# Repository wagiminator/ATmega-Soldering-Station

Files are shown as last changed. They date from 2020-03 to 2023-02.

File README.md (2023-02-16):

## !!! Warning: the version with "t" is the test version, there may be stability problems! Not recommended for production environments
## !!! 警告：带有“t”的是测试版本，可能存在稳定性问题！不建议用于生产环境

# 1. Overview
T12 焊台控制器功能介绍
T12 Quick Heating Soldering Station featuring
- 烙铁头温度实时监测
- Temperature measurement of the tip
- PID温度控制
- Direct or PID control of the heater
- 可以通过编码器进行控制温度
- Temperature control via rotary encoder
- 短按编码器进入短时升温模式
- Boost mode by short pressing rotary encoder switch
- 长按编码器进入主菜单
- Setup menu by long pressing rotary encoder switch
- 手柄震动检测（需要手柄含有震动传感器）
- Handle movement detection (by checking ball switch)
- 手柄连接检测（通过判断烙铁头温度是否能够被读取来实现）
- Iron unconnected detection (by idenfying invalid temperature readings)
- 定时器设定 - 随眠，关机时间
- Time driven sleep/power off mode if iron is unused (movement detection)
- 可以测量主控芯片电压以及温度
- Measurement of input voltage, Vcc and ATmega's internal temperature
- 在OLED上实现信息显示
- Information display on OLED
- 支持无源蜂鸣器
- Buzzer
- 允许设置不同烙铁头的温度校准值
- Calibrating and managing different soldering tips
- 设置被保存在EEPROM，掉电不丢失
- Storing user settings into the EEPROM
- 允许热插拔烙铁头，并弹出烙铁头配置选择菜单
- Tip change detection
- Support for N-Channel and P-Channel MOSFETs

## =========UI upgraded version =========

- 芯片过热以及低电压报警
- Chip overheating and low voltage alarm
- 更好的实时温度条以及实时功率条
- Better real-time temperature bar and real-time power bar
- 拥有过渡动画
- Have transition animation
- 内置屏幕保护程序
- Built in screen saver
- 屏幕翻转设置
- Screen flip settings
- 内置英文、中文语言包
- Built in English and Chinese language pack
- 开机密码设置
- System Password
- 允许设置旋钮方向
- Knob direction setting menu
- 内嵌看门狗，宕机自动重启
- Watchdog timer automatic reset the MCU

## V1.8t7 New features:

- EEPROM可用性检查机制
- EEPROM availability check

- 允许保存最大30个烙铁头的配置
- Tip change detection30 preservable soldering tip configurations

- 9段温度曲线拟合
- 9 segments of temperature curve fitting

## Links:
- Project Video: https://youtu.be/I9ATDxvQ1Bc
- Video from John Glavinos (electronics4all): https://youtu.be/4YDcWfOQmz4
- Video from LHW-createskyblue (UI-v1.6L): https://b23.tv/LiOe54
- T245 version with P-channel MOSFET by TaaraLabs: https://taaralabs.eu/atmega-t245/

# 2. Versions, Upgrades and Notes

## Soldering Station v2.0:




## Soldering Station v2.5:




## Soldering Station v2.6:




## UI-V1.8t6 UI Upgrade by createskyblue & lihaoyun6

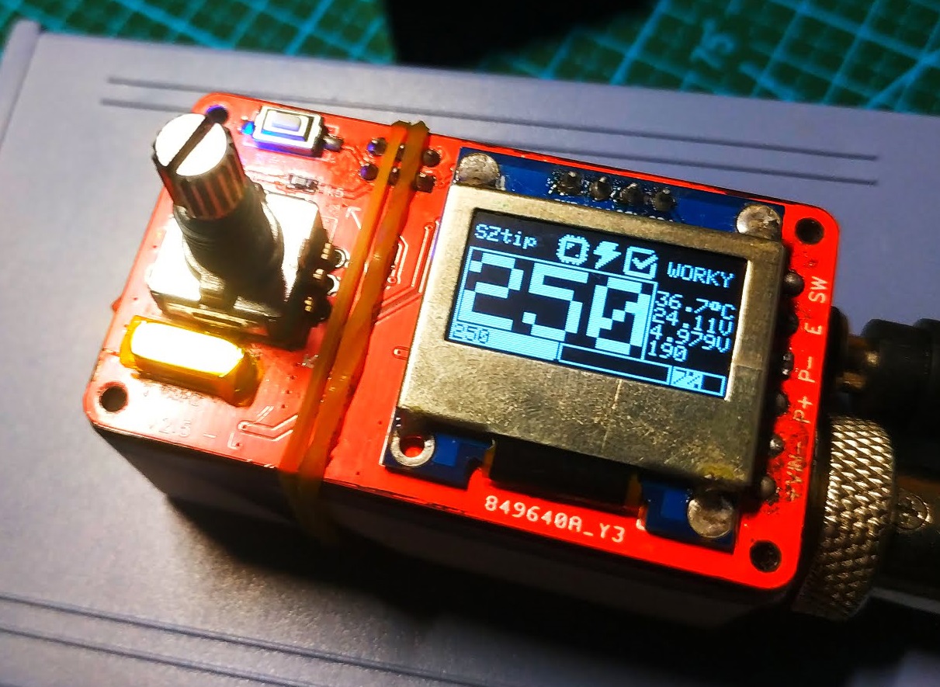
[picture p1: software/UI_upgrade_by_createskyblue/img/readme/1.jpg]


### Default control interface

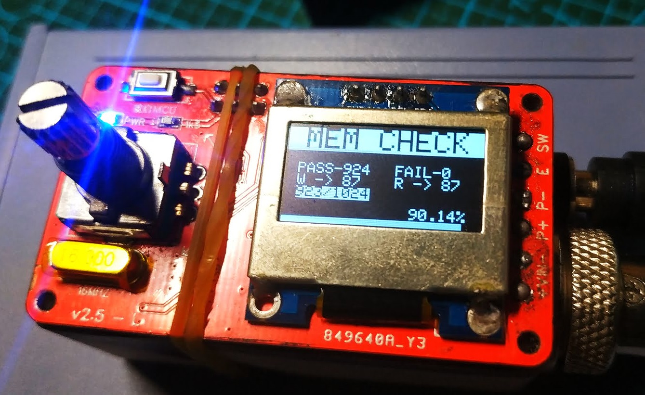
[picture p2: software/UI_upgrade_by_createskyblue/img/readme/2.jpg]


### EEPROM availability check

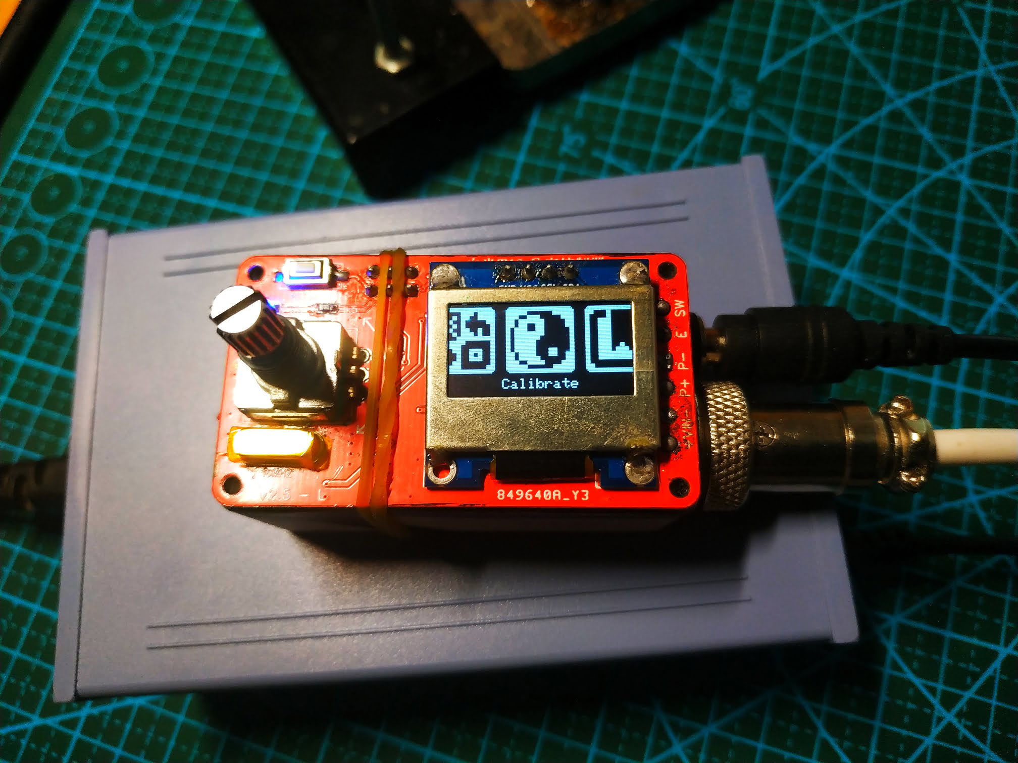
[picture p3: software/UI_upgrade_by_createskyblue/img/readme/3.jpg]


### Tip menu

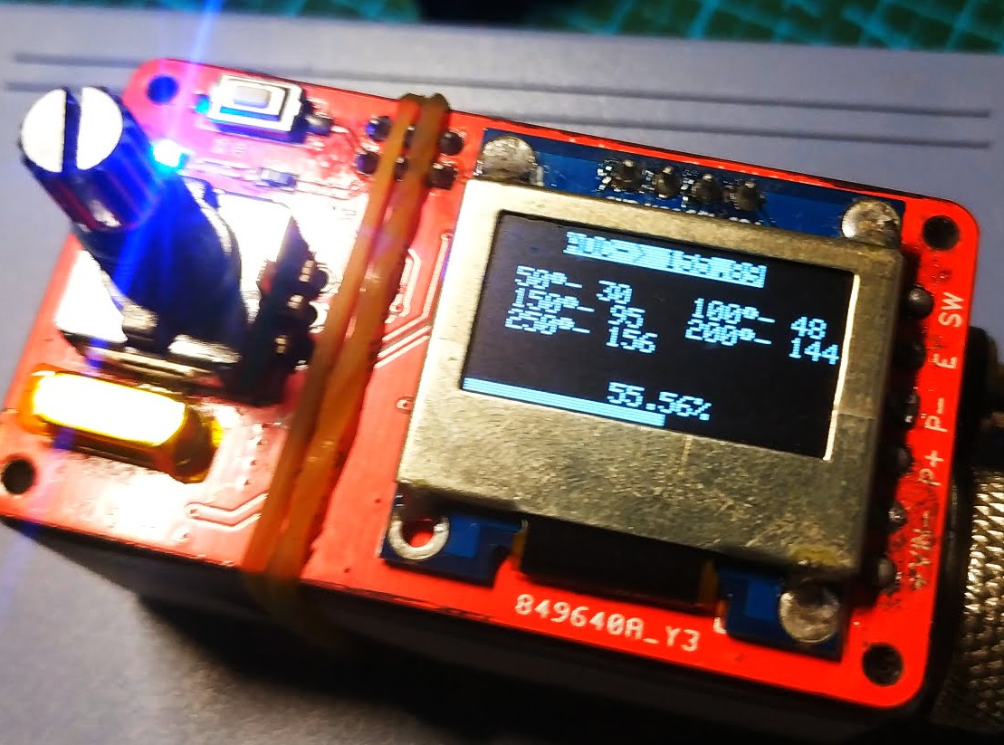
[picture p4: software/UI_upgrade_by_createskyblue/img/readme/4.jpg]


### 9 segments of temperature curve fitting & Soldering tip calibration page

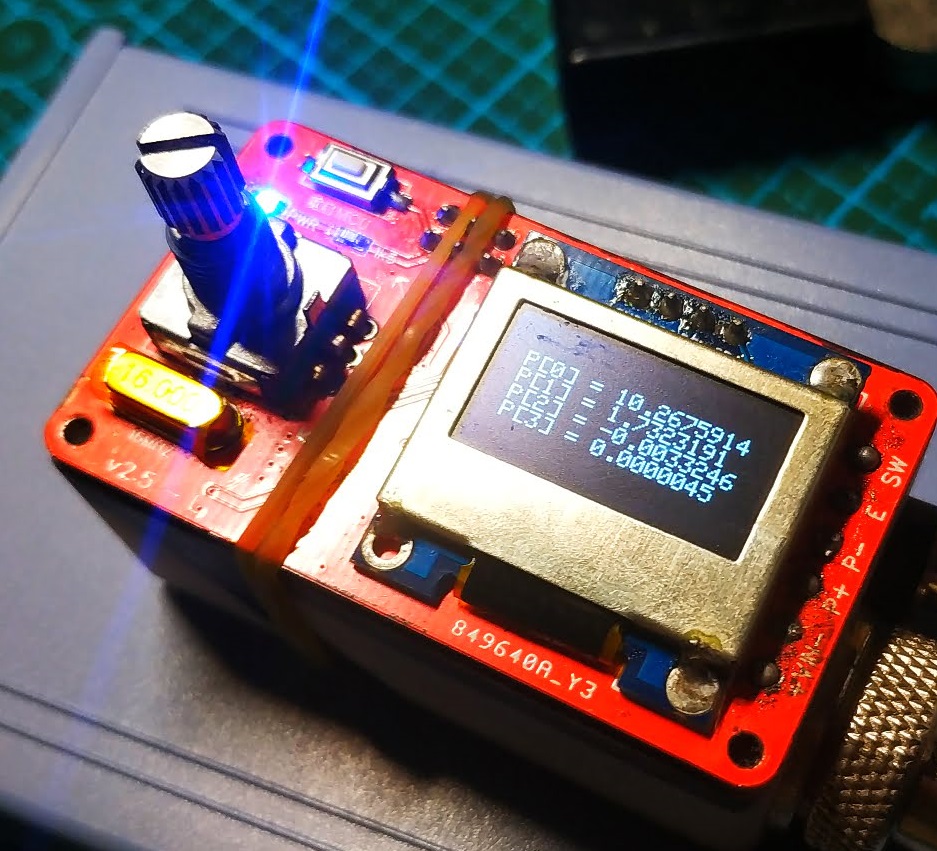
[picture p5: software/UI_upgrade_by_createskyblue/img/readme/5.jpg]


### Temperature calibration coefficient

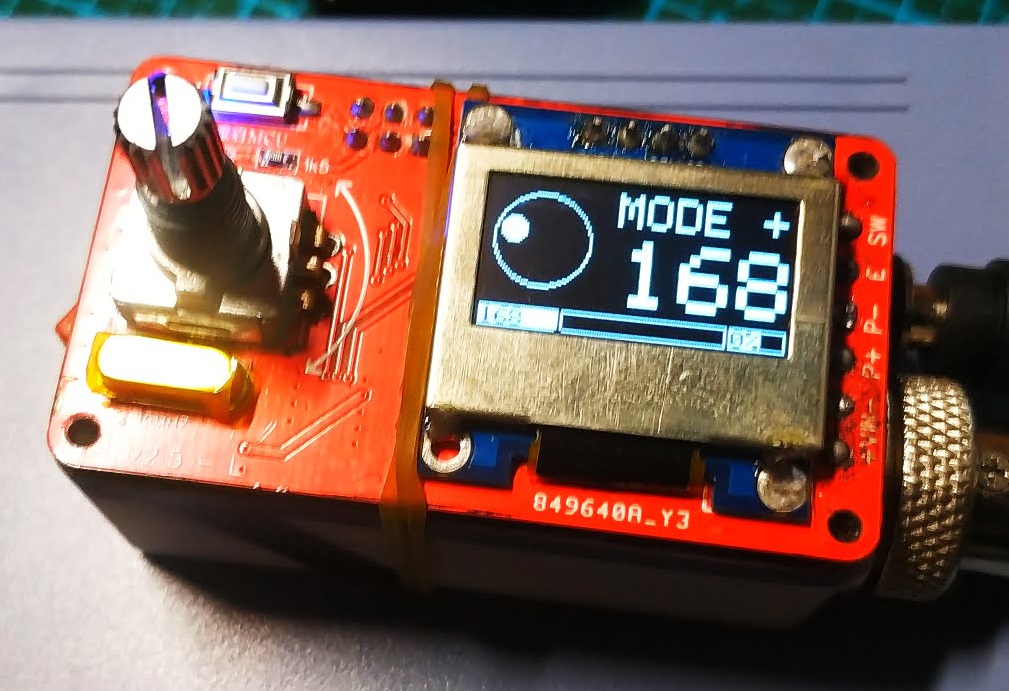
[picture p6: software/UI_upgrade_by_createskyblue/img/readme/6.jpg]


### Encoder direction regulation

Video from LHW-createskyblue (UI-v1.6L): https://b23.tv/LiOe54
	






## Notes and Errors

- In the board version 2.5 the diode D1 may overheat. To be on the safe side, the 18V zener diode D4 should be removed and the soldering station should be operated with a maximum of 20V. Alternatively, the diode D1 can be replaced with an SS54 schottky diode and the BJT Q1 with an FMMT619. 

# 3. Power Supply Specification Requirements #

Choose a power supply with an output voltage between 12V and 24V which can provide an output current according to the table below. The power supply must be well stabilized. The current and power is determined by the resistance (R = 8 Ohm) of the heater.

|Voltage (U)|Current (I) = U / R|Power (P) = U² / R|
|-|-|-|
|12 V|1.50 A|18 W|
|13 V|1.63 A|21 W|
|14 V|1.75 A|25 W|
|15 V|1.88 A|28 W|
|16 V|2.00 A|32 W|
|17 V|2.13 A|36 W|
|18 V|2.25 A|41 W|
|19 V|2.38 A|45 W|
|20 V|2.50 A|50 W|
|21 V|2.63 A|55 W|
|22 V|2.75 A|61 W|
|23 V|2.88 A|66 W|
|24 V|3.00 A|72 W|

# 4. Temperature Measurement and OpAmp Considerations #

A thermocouple (temperature sensor) is located in the T12 soldering tip. It creates a very small voltage depending on the temperature difference between the hot end and the cold junction (about 22 microvolts per degree Celsius). To measure this, the heater must be switched off since both share the same connections. The low voltage is amplified by the OpAmp and measured by the ADC of the microcontroller. The LMV358 is a very cheap and versatile OpAmp, but not the ideal choice for this task because it has a fairly high input offset voltage and is quite noisy. Although the SolderingStation also works with this OpAmp thanks to the software's smoothing and calibration algorithms, I highly recommend spending a little more money in a better one. The OPA2330AIDR or OPA2333AIDR for instance have the same pinout and can also be used with this board. They provide significantly more accurate and stable temperature measurements.






# 5. Heater High Side Switch with N-Channel MOSFET and Charge Pump #

The microcontroller switches the heater on and off via the MOSFET. Since the temperature measurement must be done over the same line and against ground, the MOSFET has to be placed between the supply voltage and the heater (high-side switch). A P-Channel MOSFET is normally used for this configuration. However, N-Channel MOSFETs usually have a lower resistance (RDS (on)), in the case of the IRLR7843 only 3 milliohms. A low resistance means a higher efficiency and a lower heat development of the MOSFET. For an N-channel MOSFET to function as a high-side switch, an additional circuit is required to maintain a positive GATE-TO-SOURCE voltage after the MOSFET is switched on. This is done using a so-called charge pump consisting of a capacitor and a diode. The principle of operation is illustrated in the following graphic by [Smallp Tsai](https://github.com/SmallpTsai):




# 6. Building Instructions #

In addition to the components for the PCB you will need the following:

- 3D-printed case
- Aviator Plug (4- or 5-pin depending on your iron handle)
- DC Power Jack (5.5 * 2.1 mm)
- Rocker Switch (KCD1 15 * 10 mm)
- Some wires
- 4 Self-tapping screws (2.3 * 5 mm)




Make sure that all parts fit nicely into the case. Solder the wires to the connectors and protect them with heat shrinks. Use thick wires (AWG18) for the power connections. Make all connections according to the schematic down below but keep in mind, that there's no standard pinout. Solder the wires directly to the corresponding pads on the pcb. To make the soldering station ESD-safe, connect the earth (E) terminal of the aviator plug to a female dupont connector and glue it into the corresponding opening on the case. Now you can connect the soldering station via a male dupont connector to an earth terminal. Upload the firmware and screw the pcb on top of the case.



The pinout shown works for the [Quecoo handles from aliexpress](https://aliexpress.com/wholesale?SearchText=quecoo+handle). Different handles may have different pinouts. If you are assembling your handle yourself, follow the scheme shown below. The video by [John Glavinos (electronics4all)](https://www.youtube.com/watch?v=DcmiFfuZw38) shows how it's done.



# 7. License #



This work is licensed under Creative Commons Attribution-ShareAlike 3.0 Unported License. 
(http://creativecommons.org/licenses/by-sa/3.0/)

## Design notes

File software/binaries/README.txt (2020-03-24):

avrdude -c usbtiny -p m328p -V -U lfuse:w:0xff:m -U hfuse:w:0xdb:m -U efuse:w:0xfd:m
avrdude -c usbtiny -p m328p -U flash:w:<name>.hex

re2: rotary encoder with 2 increments/step
re4: rotary encoder with 4 increments/step

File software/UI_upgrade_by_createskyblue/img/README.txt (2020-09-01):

感谢 千年板蓝根(github: lihaoyun6) 提供的字体文件以及相关素材！！！
Thanks for the font files and related materials provided by 千年板蓝根 (GitHub: lihaoyun6)!!!

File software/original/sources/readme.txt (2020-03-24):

Libraries:
https://github.com/olikraus/u8glib
https://github.com/mblythe86/C-PID-Library/tree/master/PID_v1

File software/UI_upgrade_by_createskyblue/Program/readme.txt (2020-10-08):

*重要提示 Important note

版本号含有"t"的代表是测试版本，不稳定不推荐上传
A version number with a "t" indicates a test version, and unstable uploads are not recommended

版本号含有多个"+" 代表是改进版本
The version number contains multiple "+" to indicate an improved version

Upload:
固件上传指令
avrdude -c usbtiny -p m328p -V -U lfuse:w:0xff:m -U hfuse:w:0xdb:m -U efuse:w:0xfd:m
avrdude -c usbtiny -p m328p -U flash:w:<name>.hex

Libraries:
用到的库文件
https://github.com/createskyblue/Arduboy2/
https://github.com/mblythe86/C-PID-Library/tree/master/PID_v1

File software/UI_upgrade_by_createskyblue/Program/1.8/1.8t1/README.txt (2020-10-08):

*1.8t1  国庆节更新目标*

1.调整简约模式的界面设计
2.加入编码器方向设定界面

3.加入自定义界面模式

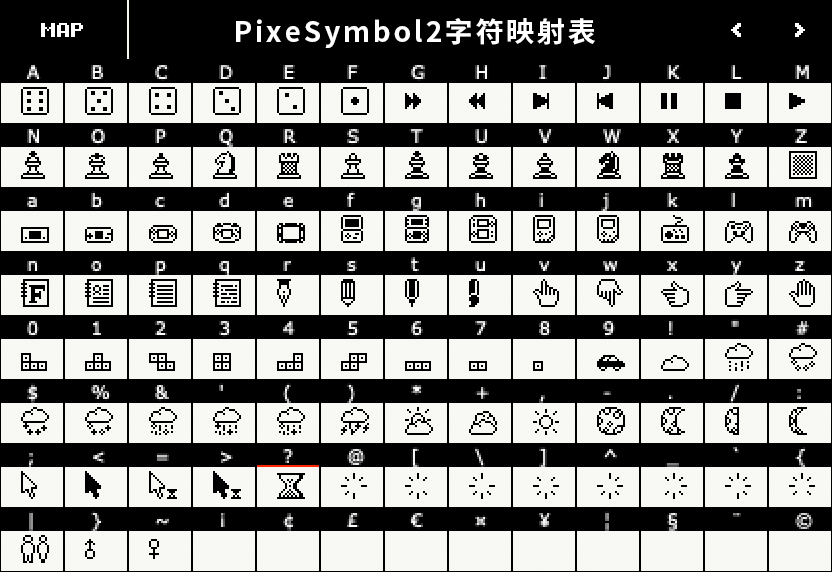
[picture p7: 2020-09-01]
software/UI_upgrade_by_createskyblue/img/PixeSymbol2字符映射表.png

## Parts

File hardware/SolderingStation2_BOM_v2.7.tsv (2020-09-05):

ID | Name | Designator | Footprint | Quantity | Manufacturer Part | Manufacturer | Supplier | Supplier Part | LCSC Assembly
1 | 1N4148W | D2 | DIODE-SOD-123 | 1 | 1N4148W-E3-08 | Vishay Intertech | LCSC | C241939
2 | LMV358IDR | U3 | SOP-8_150MIL | 1 | LMV358IDR | TI | LCSC | C63813 | Yes
3 | 16MHZ | X1 | HC-49S | 1 | X49SD16MSD2SI | Yangxing Tech | LCSC | C188201
4 | MLT-5030 | BUZZER1 | MLT-5030 | 1 | MLT-5030 | HNDZ | LCSC | C95297
5 | OLED | OLED | I2C - OLED 0.96" 128X64 | 1 | SSD1306 I2C OLED
6 | 18V | D4 | ZENER-SOD-123 | 1 | MM1Z18 | Jingdao | LCSC | C116111 | Yes
7 | 5V1 | D3 | ZENER-SOD-123 | 1 | MM1Z5V1 | SEMTECH | LCSC | C81601 | Yes
8 | 47k | R12 | 0603 | 1 | 0603WAF4702T5E | UniOhm | LCSC | C25819
9 | 1k5 | R2 | 0603 | 1 | 0603WAF1501T5E | UniOhm | LCSC | C22843
10 | 10k | R11,R13,R3,R4,R6,R7,R14,R10,R1 | 0603 | 9 | 0603WAF1002T5E | UniOhm | LCSC | C25804
11 | 1k | R9 | 0603 | 1 | 0603WAF1001T5E | UniOhm | LCSC | C21190
12 | 200k | R8 | 0603 | 1 | 0603WAF2003T5E | UniOhm | LCSC | C25811
13 | IRLR7843TRPBF | Q2 | TO-252-2 | 1 | IRLR7843TRPBF | IR | LCSC | C21988 | Yes
14 | KF350-3.5mm | P3,P2,P1 | KF350-2P | 3 | WJ2EDGVC-5.08-2P | ReliaPro | LCSC | C8445
15 | ICSP-6 | ICSP | ICSP-6 | 1 | ?
16 | 3x6x2.5 | RESET | KEY-3.0*6.0 | 1 | 3x6x2.5Red head high temperature | ReliaPro | LCSC | C46491
17 | Rotary Enc | SW1 | BOURNS_PEC11R-4XXXF-SXXXX | 1 | PEC11R-4015F-S0024 | BOURNS | LCSC | C143789
18 | 100n | C10,C1,C9,C3,C2 | 0603 | 5 | CC0603KRX7R9BB104 | YAGEO | LCSC | C14663
19 | 1u | C13 | 0603 | 1 | CL10A105KB8NNNC | SAMSUNG | LCSC | C15849
20 | 330n | C11 | 0603 | 1 | C1608X7R1H334KT000E | TDK | LCSC | C76621
21 | 22p | C5,C6 | 0603 | 2 | CL10C220JB8NNNC | SAMSUNG | LCSC | C1653
22 | 2n2 | C8 | 0603 | 1 | 0603B222K500NT | FH | LCSC | C1604
23 | 1k | R5 | 1206 | 1 | 1206W4F1001T5E | UniOhm | LCSC | C4410
24 | 47u | C4 | 1206 | 1 | 1206F476M100NT | FH | LCSC | C30349
25 | 22u | C12 | 1206 | 1 | C3216X5R1V226MTJ00E | TDK | LCSC | C342620
26 | 10u | C7 | 1206 | 1 | GMK316BJ106KL-T | Taiyo Yuden | LCSC | C92797
27 | 78M05 | U2 | TO-252-2 | 1 | ME78M05K3G | MICRONE | LCSC | C83969 | Yes
28 | PWR | LED1 | LED0603 | 1 | 19-217/BHC-ZL1M2RY/3T | EVERLIGHT | LCSC | C72041
29 | FMMT619 | Q1 | SOT-23-3_L2.9-W1.6-P1.90-LS2.8-BR | 1 | FMMT619 | CJ | LCSC | C53071 | Yes
30 | SS54 | D1 | DIODE-SMA(DO-214AC) | 1 | SS54 | Jingdao | LCSC | C123946 | Yes
31 | ATMEGA328P-AU | U1 | TQFP-32_7X7X08P | 1 | ATMEGA328P-AU | MICROCHIP | LCSC | C14877 | Yes

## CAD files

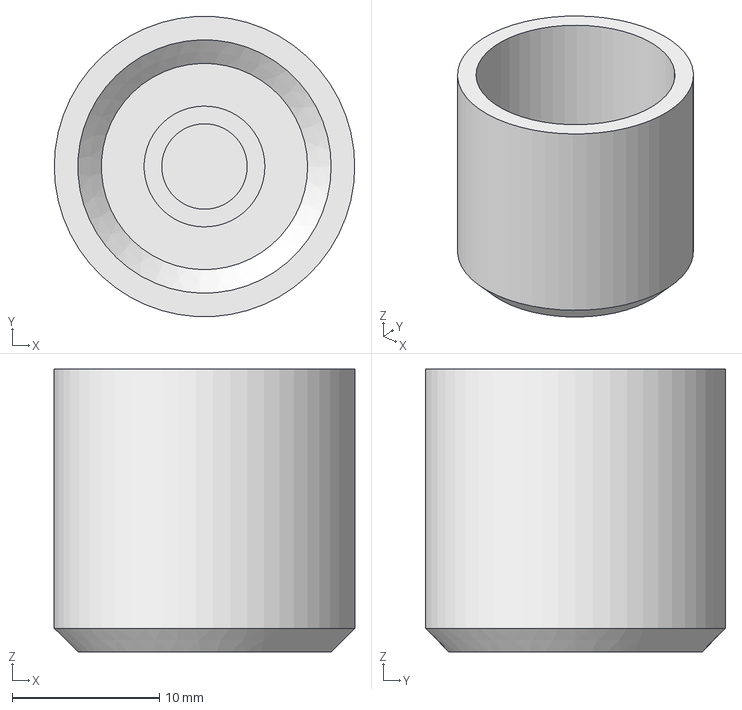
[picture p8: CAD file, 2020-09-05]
3dprint/SolderingStationV2_knob.fcstd
20.4 x 20.4 x 19.2 mm

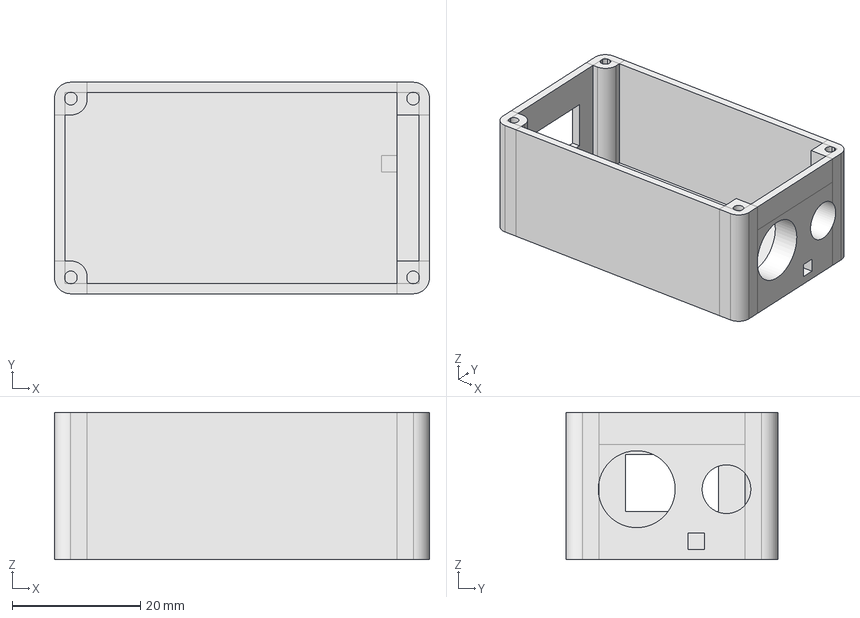
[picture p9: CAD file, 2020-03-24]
3dprint/SolderungStationV2_Case_ESD.fcstd
58.5 x 33.0 x 23.0 mm

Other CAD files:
3dprint/SolderingStationV2_knob.stl
3dprint/SolderungStationV2_Case_ESD.stl

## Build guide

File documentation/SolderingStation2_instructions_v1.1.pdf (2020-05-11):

## How to build the Mini T12 SolderingStation v2

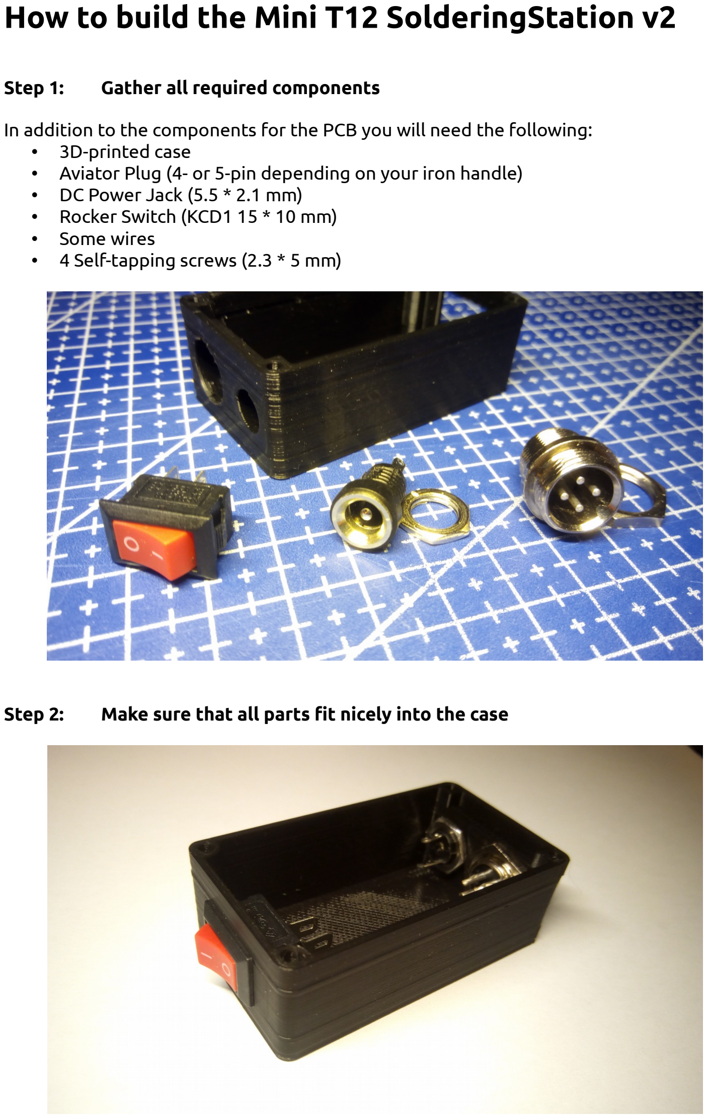
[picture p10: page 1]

Step 1: Gather all required components

In addition to the components for the PCB you will need the following:
- 3D-printed case
- Aviator Plug (4- or 5-pin depending on your iron handle)
- DC Power Jack (5.5 * 2.1 mm)
- Rocker Switch (KCD1 15 * 10 mm)
- Some wires
- 4 Self-tapping screws (2.3 * 5 mm)
Step 2: Make sure that all parts fit nicely into the case

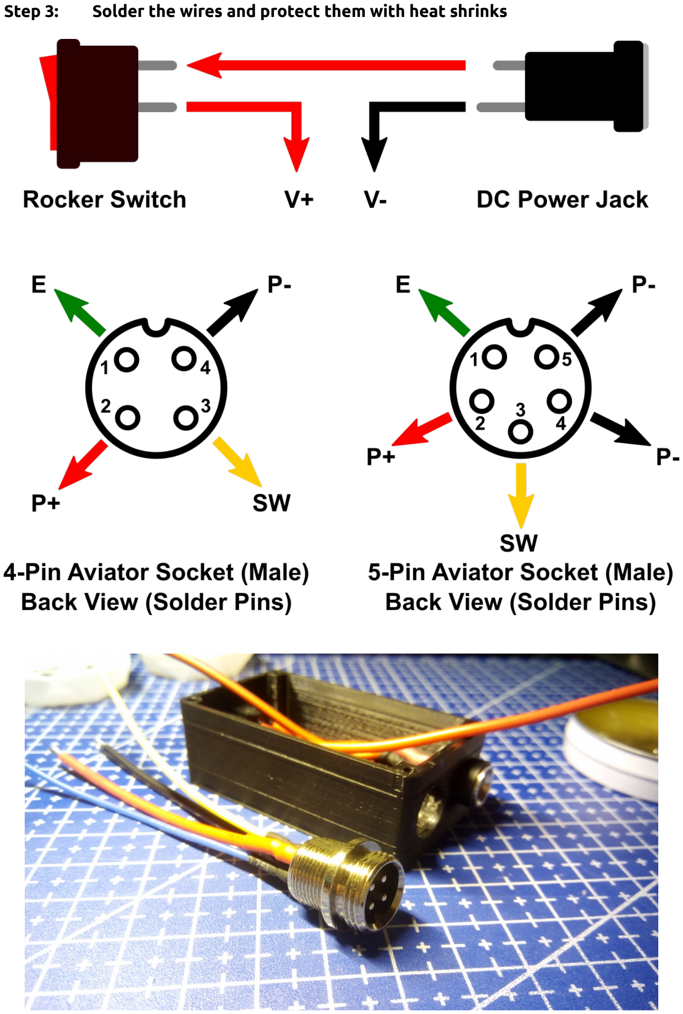
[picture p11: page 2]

Step 3: Solder the wires and protect them with heat shrinks

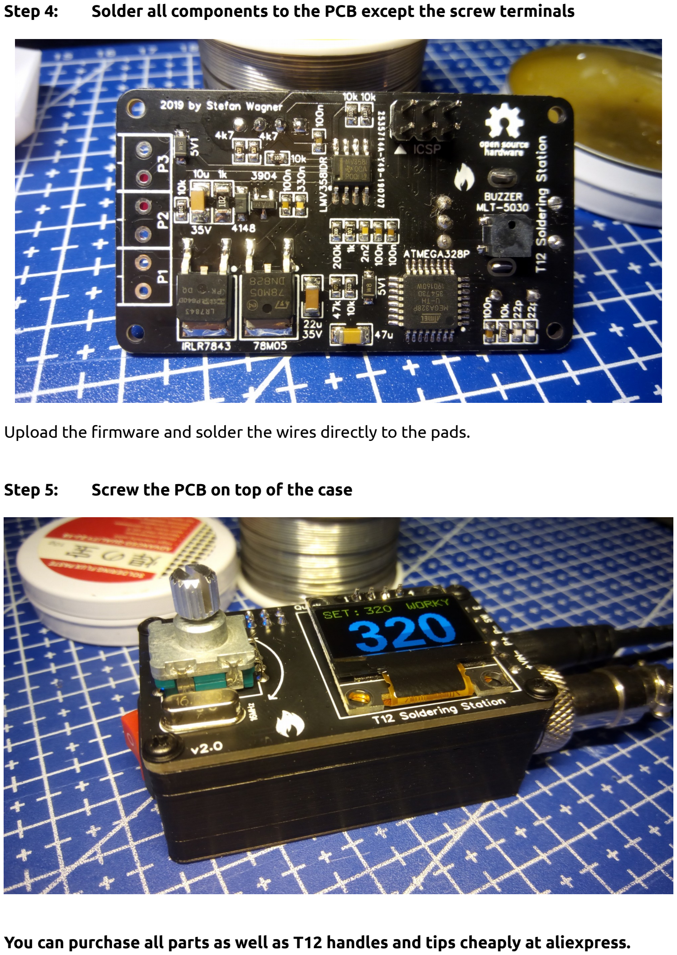
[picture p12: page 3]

Step 4: Solder all components to the PCB except the screw terminals

Upload the firmware and solder the wires directly to the pads.

Step 5: Screw the PCB on top of the case

You can purchase all parts as well as T12 handles and tips cheaply at aliexpress.

Choose a power supply with an output voltage between 16V and 24V which can provide an output current according to the table below. The power supply must be well stabilized. The current and power is determined by the resistance (R = 8 Ohm) of the heater.

Voltage (U) | Current (I) = U / R | Power (P) = U² / R
16 V | 2.00 A | 32 W
17 V | 2.13 A | 36 W
18 V | 2.25 A | 41 W
19 V | 2.38 A | 45 W
20 V | 2.50 A | 50 W
21 V | 2.63 A | 55 W
22 V | 2.75 A | 61 W
23 V | 2.88 A | 66 W
24 V | 3.00 A | 72 W

A 19V supply works best in terms of both, speed and stable temperature readings. Heat-up time to 320°C will be around 12 seconds with a 19V, 8 seconds with a 24V power supply.

SolderingStation2 Building Instructions v1.1, 2019/2020 by Stefan Wagner. Recent project files can be found at https://easyeda.com/wagiminator/z-solderingstation-smd-v2. This work is licensed under Creative Commons Attribution-ShareAlike 3.0 Unported License (http://creativecommons.org/licenses/by-sa/3.0/).

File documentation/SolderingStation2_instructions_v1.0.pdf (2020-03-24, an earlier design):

## How to build the Mini T12 SolderingStation v2

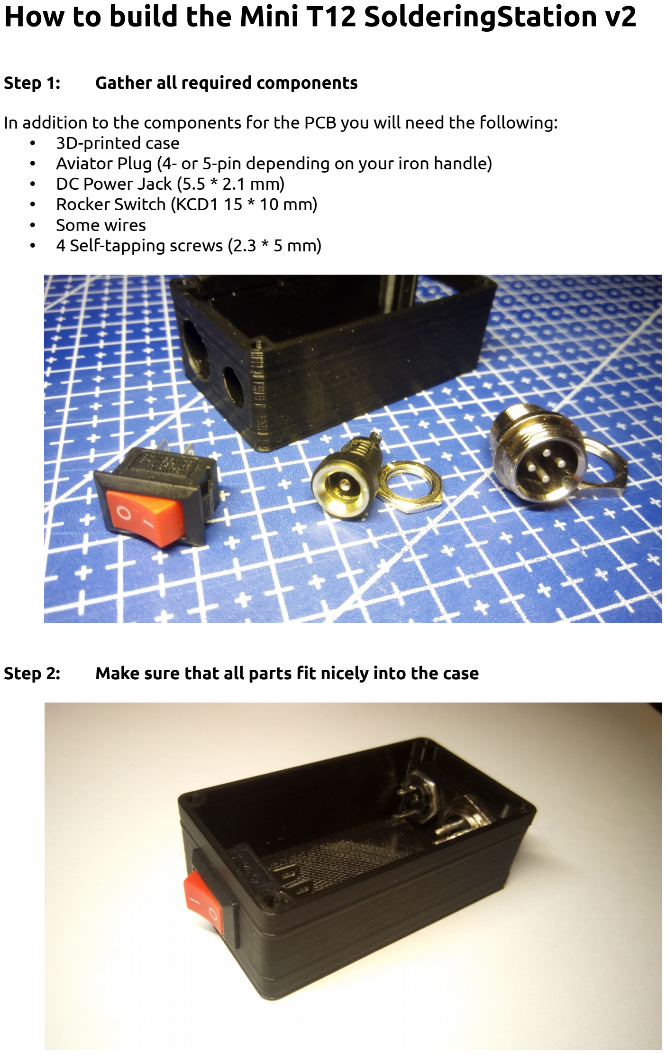
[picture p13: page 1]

Step 1: Gather all required components

In addition to the components for the PCB you will need the following:
- 3D-printed case
- Aviator Plug (4- or 5-pin depending on your iron handle)
- DC Power Jack (5.5 * 2.1 mm)
- Rocker Switch (KCD1 15 * 10 mm)
- Some wires
- 4 Self-tapping screws (2.3 * 5 mm)
Step 2: Make sure that all parts fit nicely into the case

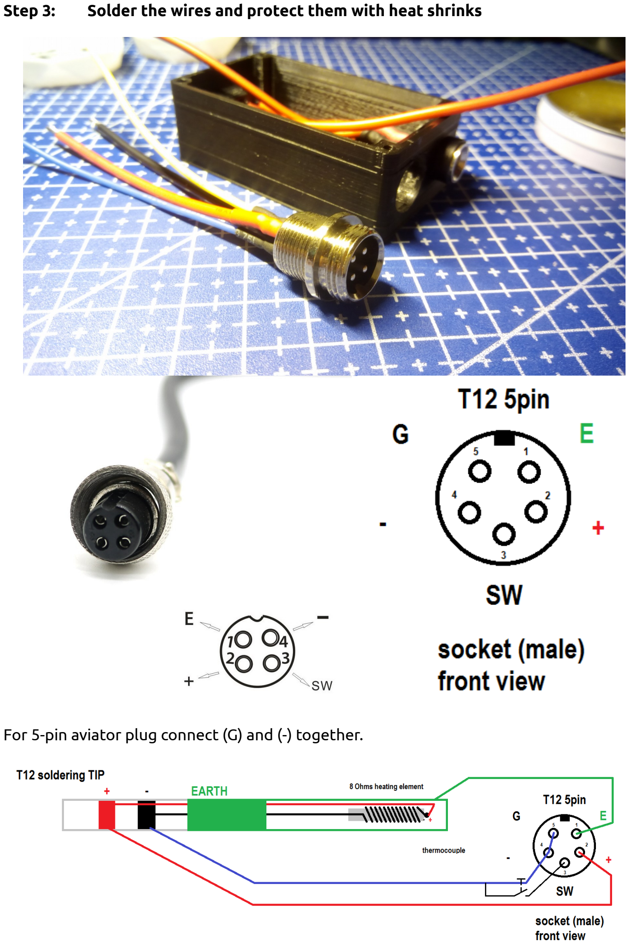
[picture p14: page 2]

Step 3: Solder the wires and protect them with heat shrinks

For 5-pin aviator plug connect (G) and (-) together.

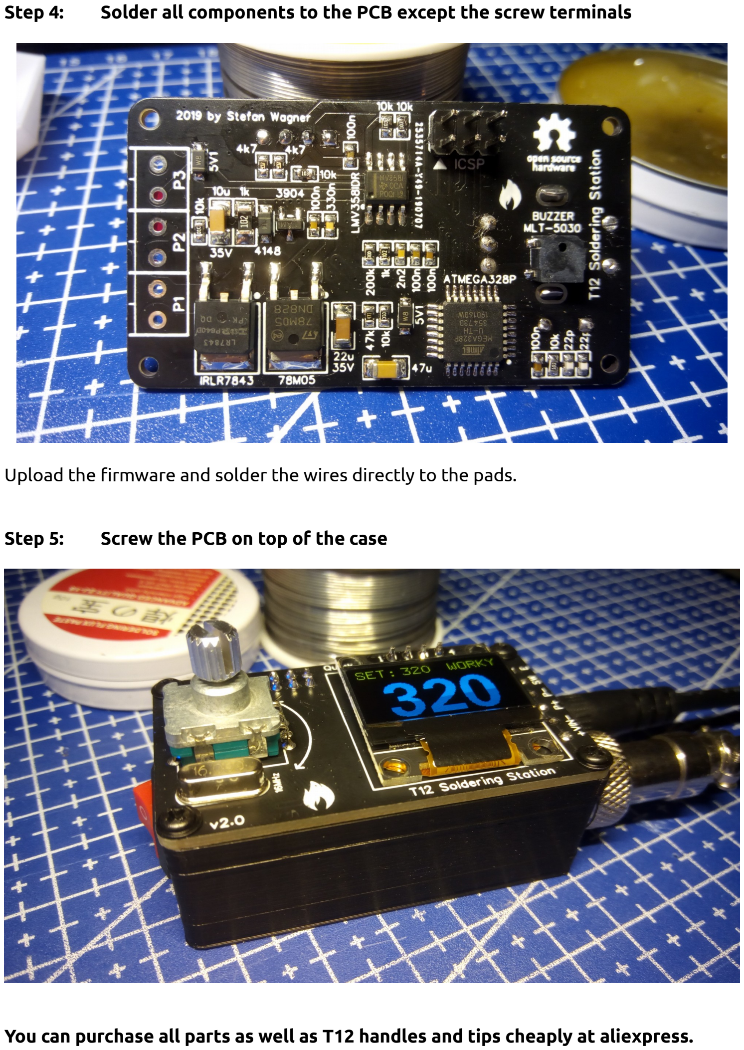
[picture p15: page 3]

Step 4: Solder all components to the PCB except the screw terminals

Upload the firmware and solder the wires directly to the pads.

Step 5: Screw the PCB on top of the case

You can purchase all parts as well as T12 handles and tips cheaply at aliexpress.

Use a well stabilized power supply that meets the following specs:

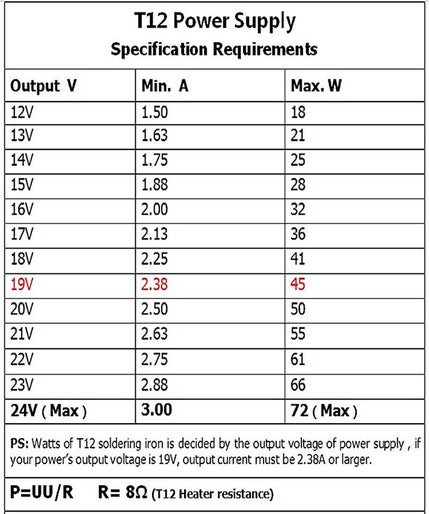
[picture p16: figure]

I recommend using at least 16V. A 19V supply works best in terms of both, speed and stable temperature readings. Heat-up time to 320°C will be around 12 seconds with a 19V, 8 seconds with a 24V power supply.

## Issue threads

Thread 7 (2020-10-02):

chinese clone handle compatibility

keiser1080, 2020-10-02:
Hi,

is your aviator plug wiring compatible with the chinese handle?
It's a bit confusing.
for example + is pin 2 and - pin 5 & 4.
on the ksger clone & other i see + is pin 5 & ground pin 4.
as you can see here [ksger](https://ae01.alicdn.com/kf/HTB1DNYkbBOD3KVjSZFFq6An9pXag.jpg)

wagiminator, 2020-10-02:
Hi,
I'm not sure if your picture is correct. I can't imagine that the tilt switch is connected to earth. However, there is no official standard. I'm using 4-pin handles from china, e.g. https://aliexpress.com/item/32925815648.html, https://aliexpress.com/item/33046441829.html, https://aliexpress.com/item/4000130747937.html, https://aliexpress.com/item/32891866988.html (all tested). If you already have a handle, you can use a multimeter to figure out the correct pinout and wire the aviator plug accordingly.

keiser1080, 2020-10-02:
> Hi,
> I'm not sure if your picture is correct. I can't imagine that the tilt switch is connected to earth. However, there is no official standard. I'm using 4-pin handles from china, e.g. https://aliexpress.com/item/32925815648.html, https://aliexpress.com/item/33046441829.html, https://aliexpress.com/item/4000130747937.html, https://aliexpress.com/item/32891866988.html (all tested). If you already have a handle, you can use a multimeter to figure out the correct pinout and wire the aviator plug accordingly.

Yes i have a handel, i have buy the following station []( https://www.aliexpress.com/item/4000183089084.html)
The station come without the tips.
I tryied using my power cord  the screen show error .
Then as soon as i recieved my tips from banggood i have tryed again.
My home fruse go down.
I tryed separatly the 24 power supply.
And the crontroler using my lab power supply then i see a blue smoke :) coming from a the controler.
I have checked the controler and i found 24v on the output of the regulator.
Conclusion the  controler is totaly broken.
So i am planning to do your controller but with a esp32 in place of the atmega.

But i am still not sure what cause the problem.
I found a shortcut on the aviator plug between the pin labeled E & pin labeled G

And now i found the ntc on the handel is also broken (the heatsrink  do not cover entierly & there is a suspicious mark)
My handel is connected like this:
pin 1 : red   (first pin from right of the tip)
pin 2 : withe connected to ntc toward the pin 5
pin 3 : green  (third pin from right of the tip)
pin 4 : blue connected to the mercury switch toward pin 3
pin 5 : black  (second pin from right of the tip)

pin label on my solder station:
1:+
2:N
3:S
4:N
5:G

Closed 2020-11-18.

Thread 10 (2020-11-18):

make bom searchable

keiser1080, 2020-11-18:
Hi,
i just discover that github can make the csv & tsv file searchable.
It's automatic.
In order to make the bom searchable you have tu remove the double cote.

https://docs.github.com/en/free-pro-team@latest/github/managing-files-in-a-repository/rendering-csv-and-tsv-data
Thanks again for this project!

wagiminator, 2020-11-18:
Hi,
thank you, it's great. The problem are not the quotation marks, I had to rename the file extensions from .csv to .tsv because the files are tab-seperated.

Closed 2020-11-18.

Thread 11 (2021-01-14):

Grounding problem and 12V power supply compatibility

waitlamp, 2021-01-14:
Many DIY T12 Soldering Stations Use Switch Mode Power Supply.
When use an ungrounded SMPS, Y Capacitor can conduct a 50 / 60 Hz AC to metal surface, usually the half of 220 V/ 110 V  voltage. Grounding is a  easy and effective way to avoid leakage current and circuit damage ( rarely occurs ), but in some cases grounding may not be feasible. ( e.g. buildings lack of PE line rarely )

#### I have heard many solutions such as:
+ Grounding to metal water pipe
+ Use a battery power supply hardware version
+ Use linear power supply
+ Use antistatic plastic floor
+ Use Isolation transformer

**some of them may not safe and useless*

After considering safety and price, I decided to try another way. Use a power bank provide the power to T12 soldering. When using specific cable accessories, QC protocol supported power bank can easily provided 12V voltage, when use a PD protocol supported power bank, it can be higher ( In fact, some hardware versions even use a MacBook power adaptor as power supply and casing of T12 soldering station ). especially the former is much cheaper than series battery packs, and more portable and removable. Connect with a power bank, T12 can be used as a portable soldering station.
I found that some people have tested it on some commercial versions of the DIY T12 soldering station, and it works well except for a slightly longer heating time, even for some of the DC socket versions marked with 16-24 volts.

What about this soldering station?

The document requests power voltage 16V - 24V. Will it works properly at 12V?
If it can work, could you please add 12V power supply specification to the document?

thanks.

wagiminator, 2021-01-14:
So far I have only tested the soldering station with 16 - 24V. Basically, it should also work with 12V, but then the power is only 18W. If, as you say, it also works with 12V with other T12 stations, then it should not be any different with this one, as it essentially depends on the soldering tip, not the soldering station. Anyway, if I find the time on the weekend, I'll test it out. If I can solder with 12V reasonably well, I will adapt the information in the description accordingly.

Closed 2021-01-20.

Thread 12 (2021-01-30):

Is KSGER 5 pin handle compatible

ariefadha, 2021-01-30:
Sir, can you give me schematic for the handle wiring to T12 bits? its seems KSGER handle have difference wiring, and it has NTC. but is it you design need NTC?

If the wiring are difference i need schematic so i can rewire the KSGER handle

Here a forum page that show KSGER handle wiring :
https://www.eevblog.com/forum/reviews/stm32-oled-digital-soldering-station-for-t12-handle/75/

Thanks

wagiminator, 2021-01-30:
I suspect they have the same pinout. Nevertheless, to be on the safe side, you should check it with the multimeter. The earth pin should be conductive with the soldering tip. There should be a resistance of around 8 ohms between (+) and (-) pin. Depending on the inclination of the handle, there should be either a conductive or no connection between SW and (-). The resistance between NTC pin and (-) should be well above 8 Ohms. The NTC pin can be left unconnected or can be connected to (-). In the documentation folder there is a tip schematic in the intructions_v1.0.pdf.

JManDoo, 2021-05-21:
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

Here is the pinout I used for my KSGER Handles

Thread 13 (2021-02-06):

T12 Thermocouple uV per degree Celsius question

SmallpTsai, 2021-02-06:
Hello,
In the readme, it said the delta is roughly **40** uV per degree Celsius
but that is no match to the default calibration temp in firmware.
Please help to correct me If my calculation is wrong.

0. Vcc = **5V**
1. the gain of opamp is set to **201** (1 + 200K/1K)
2. default calibration:
   - 200/216 ->   (200 * 5 * 1000000) / (1024 * 201 * 216) = 22.49
   - 280/308 ->  (280 * 5 * 1000000) / (1024 * 201 * 308) = 22.08
   - 360/390 ->   (360 * 5 * 1000000) / (1024 * 201 * 390) = 22.42

so the actual delta should be ~**22**

Is there any calculation error above?
Please help me to understand the logic.
Thanks !!

wagiminator, 2021-02-06:
You're right, there's a mistake in the description. I will correct that. The 40uV was based on the assumption that there is a k-type thermocouple in the T12 soldering tip. But that is obviously not the case. The corresponding values in the software are derived empirically and have worked so far.

SmallpTsai, 2021-02-06:
thanks for your answer!

Closed 2021-02-06.

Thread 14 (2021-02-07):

charge pump question

SmallpTsai, 2021-02-07:
Hello,

I am studying your "charge pump" design, please correct me if my understandings are wrong.
Thanks a lot!

(based on board version v2.7)
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

**Left:**
D9 on -> Q1 on, current go through Q1, so Q2 Vgs is 0, Q2 off.
C7 is charged to full (~24v if ignore D1 voltage drop)

**Right:**
D9 off -> Q1 off, C7 start to discharge, Q2 Vgs become 24V, Q2 on.
(Vsource = ~23v, Vgate = ~47v)

**part requirement:**
Q1: Vce need to handle > 47v, therefore choose FMMT619
C7: require > 24V voltage
D1: require > 24V reverse voltage (in discharge scenario)
D4: 18V zener is to protect Q2 gate, IRLR7843 max Vgs = 20V

Thanks.

wagiminator, 2021-02-07:
Precisely! The drawing is great, can I use it in the description? Maybe that will help others too.

SmallpTsai, 2021-02-07:
sure, please feel free to use it.
thanks very much for answering and this interesting project !!

Now that everything is clear, I will try to make my own clone soon :)

wagiminator, 2021-02-07:
Many Thanks! I wish you every success with your version and look forward to hearing from the result.

Closed 2021-02-07.

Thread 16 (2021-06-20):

Where's the PCB for P-Channel Mosfets?

gitercn, 2021-06-20:
I see there are some recent commits named "Added support for P-Channel Mosfets (by TaaraLabs)".  Where's the PCB for it?

wagiminator, 2021-06-21:
TaaraLabs and some other users made their own versions with P-FETs. This is now supported by the software. But I don't have a version with P-channel MOSFET myself.

TaaraLabs, 2023-02-14:
Here is our board version that uses P-FET and uses HIROSE socket for JBC T245 irons.
https://taaralabs.eu/atmega-t245/

wagiminator, 2023-02-16:
Nice, I'll put the link on the main page.

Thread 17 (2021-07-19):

What is the role of the op amp on the right side of lmv358？

Eddddddddy, 2021-07-19:
I am trying to understand the right op amp. I don’t know why you design it like this. I'm really not good at this.
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

wagiminator, 2021-07-19:
Hi, the second OpAmp of the LMV358 is not used. An unused OpAmp should not float, as this can interfere with the OpAmps in use or, in the worst case, lead to its destruction. The two resistors stabilize the second OpAmp by forming a unity gain amplifier (or buffer) with VCC/2 as a fixed positive input value.

Eddddddddy, 2021-07-20:
Thanks for this answer. I got it!

Eddddddddy, 2021-07-20:
by the way. Can I use OPA333 replace LMV358? I rebuild the PCB project. OPA333 is much smaller than LMV358.

wagiminator, 2021-07-21:
Yes, of course, that should work fine.

Eddddddddy, 2021-07-23:
thanks！！

Closed 2021-07-23.

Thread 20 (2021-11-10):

Some questions about P+

SMU-Terry, 2021-11-10:
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
the P+ net actually directly connects with GND, is that correct? hope to get a reasonable answer, thanks

wagiminator, 2021-11-10:
No, it doesn't. Connections are marked with a junction dot: https://www.autodesk.com/products/eagle/blog/top-10-tips-draw-next-schematic-design-like-pro/

SMU-Terry, 2021-11-12:
thank you so much, I've got it, and I see that compare to the low version, you add D4 as a voltage regulator in Version 2.7, may I ask where is this idea comes from?

wagiminator, 2021-11-13:
I added that to protect the MOSFET. The Zener diode D4 limits the voltage between the gate and source of the MOSFET to about 18V. Since the maximum gate-source voltage of the MOSFET is 20V, but this is exceeded at higher supply voltages of the soldering station, this could lead to damage to the MOSFET in the long term without the diode.

SMU-Terry, 2021-11-14:
thank you so much!

Closed 2021-11-14.

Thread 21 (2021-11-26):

some questions about operate amplifier!!!

SMU-Terry, 2021-11-26:
first, thank you very much for author's answer about last question, i am really a freashman about this but eager to revive your project, and the procceeding is going to 50%
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
and now i have some theoretic question about the amplifier, why do you choose these risitors and capacitor to amplifing the thermometer value, and why does the diode directly connect to the GND?
thanks again!

wagiminator, 2021-11-27:
Looks cooool! D1 (on your schematic) limits the voltage on the positive input of the opamp to around 0.6V (forward voltage of the diode). If the soldering tip is powered, the voltage would be otherwise 24V, which would destroy the opamp. 0.6V is more than enough, the voltages created by the thermocouple are far below. R8 limits the current passing the diode. (I <= (24V - 0.6V) / R8 = 2.34mA). C11 and C12 reduce the noise. C12 must be quite low, because it can only discharge via R8 (RC discharge time ~ 5 * R8 * C12 = 110µs). C11 was determined empirically. R6+R7 and R9 form the negative feedback of the opamp, setting its gain to (R6+R7+R9) / R9 = 201.
The board is quite small in order to be able to sufficiently separate the analog from the digital area; at least I wasn't able to do this at the time - at that point I had only been dealing with electronics for about half a year. Before that I didn't even know what an opamp was ;-)

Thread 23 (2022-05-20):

Soldering_Station v2.7 flashed BUT no Output on Display

suizideFloat, 2022-05-20:
Dear @wagiminator ,

thanks for the great project.
I managed to build the PCB and solder all components. Flashing process via an Arduino UNO seems successful, but the (new) display stays dark.

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

I haven't connected any wires to V,P,E and SW yet, but the display should show something when the board is powered via ICSP right?
Can I test the display in any way?

wagiminator, 2022-11-24:
Yes, the display should show something. Are all connections correct, has the correct display been used, does it work with other programs?

coldfire0101, 2023-02-24:
im having the same problem. have tried several different sketches with arduino ide and hex files with avrdude but nothing happens on the screen, ive also tried different screens. all i get is the led lighting up on the solder station pcb

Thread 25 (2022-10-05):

5V Voltage regulator

dahayer, 2022-10-05:
Can i use a buck converter (step down)  instead of 78m05 for better efficiency and less heat ? thanks

wagiminator, 2022-10-07:
Hi, due to the quite low current consumption of the circuit, the efficiency and heat generation are negligible. However, a linear regulator generates significantly less noise than a switching regulator, which allows for a cleaner temperature measurement. If you still want it, V1 of the soldering station was implemented with a buck converter.

dahayer, 2022-10-07:
Thank you for your response.

Closed 2022-10-07.

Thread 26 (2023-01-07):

JBC c210 handle

coldfire0101, 2023-01-07:
is it possible to use a jbc c210 handle and tip, from what i have seen the jbc only has 3 wires

wagiminator, 2023-01-15:
Sorry, I'm not familiar with the c210 tips.

coldfire0101, 2023-01-15:
thanks for responding. this is what i have for c210 tips, whats throwing me is the pic shows sense a on positive and sense b on negative, otherwise its pretty much the same as t12 tip i think
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

wagiminator, 2023-01-18:
Looks very similar to the T12 tips, except for the TC, but that's not used anyway. There is obviously no tilt switch. I would say try it out.

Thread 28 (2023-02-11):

Compiling upgraded UI

phpbbireland, 2023-02-11:
No issues with original code but when compiling the new UI version, I get errors relating to Arduboy2 (6.0.0)...
Just to check, it will compile in Arduino IDE? (1.8.15)...

Errors relate to: TXLED0, TXLED1 not being defined...
Any help appreciated... Mike

wagiminator, 2023-02-12:
New UI is developed and mainained by createskyblue: https://github.com/createskyblue. So I suggest asking him.

phpbbireland, 2023-02-13:
Much appreciated, thank you for the reply, will check  the link.
Many thanks for the project (building a DIP version as I can't find TQFP stock)...

wagiminator, 2023-02-16:
You're welcome ;-)

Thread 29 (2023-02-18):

PID buzzing noises.

dahayer, 2023-02-18:
I have a strange buzzing noises (not from the buzzer) when using PID controlling, but  everything works like a charm.
I cannot find the responsible component. Any help will be appreciated. Thanks

wagiminator, 2023-02-21:
Strange. Is the noise coming from the soldering station or another device nearby?

dahayer, 2023-02-22:
Its from the soldering station i have recorded the noises with my phone if you want to hear it.
[https://drive.google.com/file/d/1bfbQFNnSnpNc9TIUcPRwxzufM4XHLMXw/view?usp=sharing](https://drive.google.com/file/d/1bfbQFNnSnpNc9TIUcPRwxzufM4XHLMXw/view?usp=sharing)

wagiminator, 2023-02-22:
This could be one of the ceramic capacitors (singing capacitors phenomenon), possibly C7 or C13. You can try using capacitors with the same values but from different manufacturers, or change the PWM frequency in the code.

dahayer, 2023-02-22:
Thank you very much for your help.

Closed 2023-02-22.

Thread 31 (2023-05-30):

map() logic of temperature calibration?

SmallpTsai, 2023-05-30:
Hello:

I found below lines interesting:
https://github.com/wagiminator/ATmega-Soldering-Station/blob/master/software/original/sources/SolderingStation2_u8glib_v1.9.ino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

according to arduino.cc, map syntax are
`map(value, fromLow, fromHigh, toLow, toHigh)`

so, should it be
`map (RawTemp,   21, CalTemp[CurrentTip][0], 0, 200);`
?
please correct me If I misunderstand the map logic here.

Thanks.

wagiminator, 2023-05-31:
Hi, the function maps the measured ADC value to the calibrated temperature. For example, CalTemp[0] is the calibrated temperature at a measured ADC value of 200. This means that the value 200 must be mapped exactly to this temperature and not the other way around, which is the case here.

SmallpTsai, 2023-06-01:
hi,

> CalTemp[0] is the calibrated temperature at a measured ADC value of 200

Ok, I did misunderstand the calibration process.

I thought the process is:
1. During calibration, you have to rotate encoder until tips thermometer read 200 degree (step 1).
2. CalTemp[0] is the measured ADC value when calibrated temperature reach 200.

But the correct process is:
1. During calibration, the station will hold at ADC value 200 (step 1), you have to rotate encoder so the number displayed match tips thermometer's reading.
2. CalTemp[0] is the calibrated temperature at a measured ADC value of 200

Thanks for clarification!

Closed 2023-06-01.

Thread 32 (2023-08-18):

Uncontrolled heating of the soldering iron head, power indicator flashing

LLC-zh, 2023-08-18:
When I solder the entire board and connect the 24v3a power supply, everything looks normal, but when I insert the soldering iron tip it goes black, the power indicator blinks, and the iron tip heats up. I don't understand why this is, I need help, thank you.

LLC-zh, 2023-08-20:
To add, 12v1a is fine, just slow to heat up, but 24v3a still doesn't work.

wagiminator, 2023-08-20:
I suspect that the power adapter is a bit overwhelmed at 3A and switches off temporarily, which would also explain the blinking of the power LED. You can check my theory with a multimeter: measure the input voltage at the station and see if the voltage fluctuates. If so, try a different power adapter.

LLC-zh, 2023-08-20:
When the soldering station is unloaded I measured 24v on the lr7843, 5v on one end of the 78m05 and 24v on the other, 24v on the vin,no voltage on the P+. When I insert the soldering iron tip all the voltages become unstable.

wagiminator, 2023-08-20:
So I think it's the power adapter. Do you have a lab bench power supply?

LLC-zh, 2023-08-24:
Yes,you are right,I bought a new power adaptor,it worked fine,thank you again.

wagiminator, 2023-08-30:
Great!

Closed 2023-09-13.

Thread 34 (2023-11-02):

No "issue" only a feedback...

ulrichloose, 2023-11-02:
A wonderful circuit that is still very relevant... I modified the circuit for a different type of display and it works just great.

However, I changed two things:

I think the thermocouple amplifier is suboptimally designed. In my opinion, the 1uF capacitor at P+ is rather unnecessary and ensures that the entire board "chirps" with the PCM frequency. The filter effect with an 8 ohm heating element is marginal. I also think the 2n2 capacitor is placed suboptimally. Its effect is many times higher when used in parallel with R8 200K and significantly increases stability.

Since the 490 Hz PCM frequency "annoys" me because of the noise, I changed the frequency via

TCCR1B = TCCR1B & B11111000 | B00000100; // for PWM frequency of 122.55 Hz

which just minimizes the "noise nuisance" and has no impact on the function.

A simple single OP LMV321RILT is used as the OP and it really works without any problems.

I think the removal of the switching power supply with the replacement 78M05 a pity... At least with my display/processor, almost 2 watts are "wasted", which increases the temperature significantly. Since I wired the whole thing as a prototype on a stripboard, I installed the 7805, but later connected a typical China stepdown module to reduce the 24 V to 8 V. Since the converter clocks at 1 MHz, this has no measurable impact on the stability of the thermocouple amplifier.

But this is just a suggestion for own experiments/changes...

wagiminator, 2023-11-02:
Hi, thank you very much for the many tips. Yes, if I were to develop the soldering station again with my current knowledge (it was one of my very first projects back then - and I'm not a trained electronics engineer!), I would do a lot of things differently. However, after many hundreds of hours of soldering, which this station has done faithfully and reliably without any complaints, I, on the other hand, tell myself that I should let things rest for a while and not continue to optimize them to death. But I'm very happy when others take up the design and improve it.
Regarding your additional question: I seem to remember that the internal voltage reference of the ATmega has a lower accuracy than the 5V voltage regulator. But maybe I'm wrong.

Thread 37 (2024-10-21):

1.8t7 problem

dh645a, 2024-10-21:
1.8t7   Thank you, I successfully copied one, but I found a problem. When MainScrType==1, it is normal. When MainScrType==0, the temperature control is unstable. I can't find any problem with the code. Why?

wagiminator, 2024-10-21:
I haven't worked with the code for several years now. It’s possible that the different time requirements of the two display options could lead to variations in the PID calculation due to differing calculation intervals. However, I’m not aware of this problem ever occurring for others.

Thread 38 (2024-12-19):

t12

AQR0124, 2024-12-19:
The soldering iron suddenly flashes the indicator light when opened, and the external adjustable power supply also keeps flashing.  Why is that?   What should I do?

wagiminator, 2024-12-20:
Hard to say without more information. Maybe the power supply can't provide enough current, or there's a short circuit somewhere. Of course, it could also be something else...

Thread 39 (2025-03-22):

V2.6 display (not an issue, just asking)

doglevski, 2025-03-22:
Hi.. I love your work! But how to get display like v2.6?? I downloaded the files, but I cannot find the v2.6 version.

wagiminator, 2025-05-02:
Hi, I'm sorry — I still use the soldering station regularly, but I haven't dealt with the hardware or software in probably five years. So unfortunately, I can't help you with your problem off the top of my head. At the moment, I just don't have the time to dig back into it.

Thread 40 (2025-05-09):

Weird crashesh when giving 20v and solder heating up more then 500°c

Rtyuakatsuki, 2025-05-09:
Hallo i have problem about when using 20v power supply or 19v+
It pretend weird when give power more then 19v

How can i fix it ?
I see your update just pull off (not use the zener 18v)

I kinda hesitant about it
And i wanna try the 20v power
I need faster heating
That why i ask for the solution what i need to do to fix it

I use board from local youtuber i got
Fareed read
Here the link board schematic

https://blogger.googleusercontent.com/img/b/R29vZ2xl/AVvXsEitz7ZCWq4CHpV2WZGww2bgKEEEbje4CBCZLly9iTcXJruOM4NMSV36XI12CHHk9Jenuw0BcbYYxRtse0hr5YZCM6x_k3Vh-BbzjC0wccpH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

wagiminator, 2025-05-11:
Have you tried using a different 20V power supply? The Zener diode is only there to protect the MOSFET.

Rtyuakatsuki, 2025-05-11:
I tries 2 power supply
First 19v 60 watt laptop power supply from asus
And second from lenovo 20v powersupply with power 240watt

Yes got same problem
After some minute it weird glitch came out and messed up
The value default temprature or adc reading

And i check the adc reading also weird
When i turn on the board adc reading was started with
250+ value

When i plug cheap 12v 3a power supply it was running good

And after couple hour after i posted that
I check the ic pin d10 sleep mode
It shorted to ground
So i was ordering alternative
Atmega328p
LGT8F328p

Hope can work on it

So the main question
What make it happen ?

And more detail
I tried search about ADC problem
With power supply
It cause by noise from the power supply

But it kinda weird
Expensive server power supply
Have bad noise isolation
And the cheap 12v 3a can handle well

So i was rethink again
Its not from power supply i think there something wrong in circuit but i dont know where

Fyi
I already ordered
Ss54
And fmmt617(i dont know it would work or not but i just wanna try because in local supplier i live
I cannot found it

Rtyuakatsuki, 2025-05-19:
Update

After changhing
Transistor to fmmt617
And diode schottky ss54

Replace atmega328p ic
I have 3 ic brand new ic

Got weird on off everytime pid used

Only pid

Direct control
Nothing wrong with it

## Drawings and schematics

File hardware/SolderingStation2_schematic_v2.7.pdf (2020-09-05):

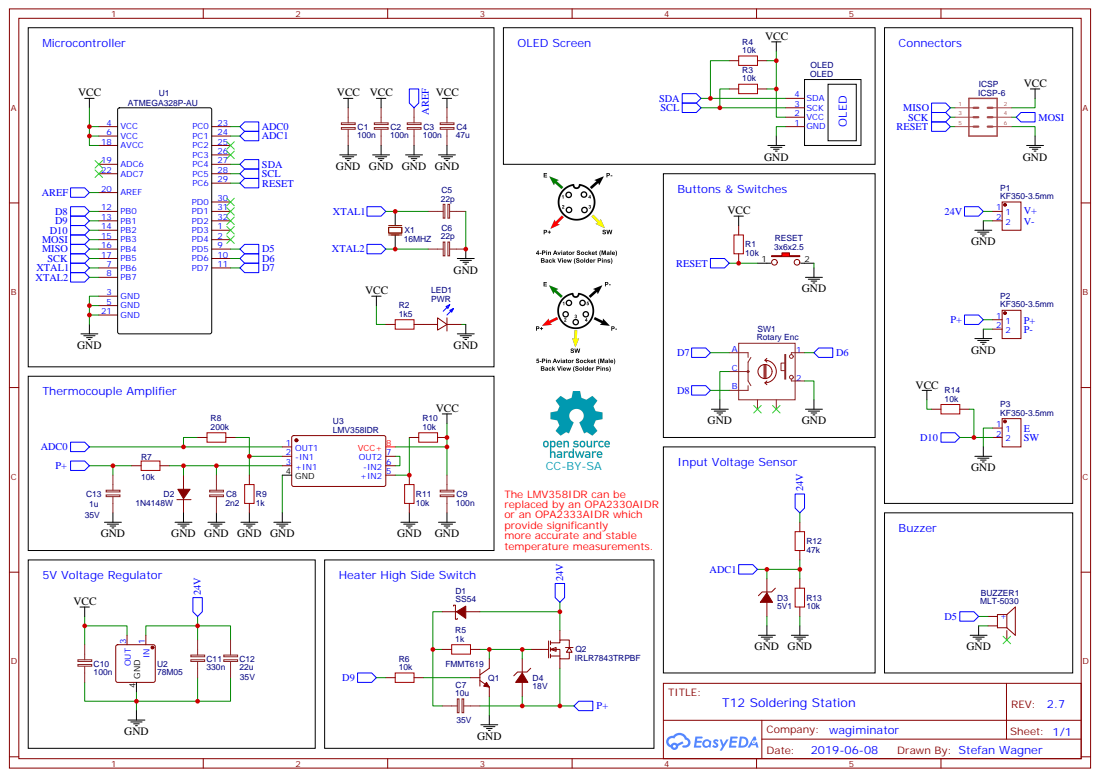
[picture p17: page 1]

GND GND

The LMV358IDR can be
replaced by an OPA2330AIDR
or an OPA2333AIDR which
provide significantly
more accurate and stable
temperature measurements.

Heater High Side Switch

Drawn By: Stefan Wagner

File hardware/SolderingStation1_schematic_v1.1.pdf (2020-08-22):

### VCC

### GND GND GND GND

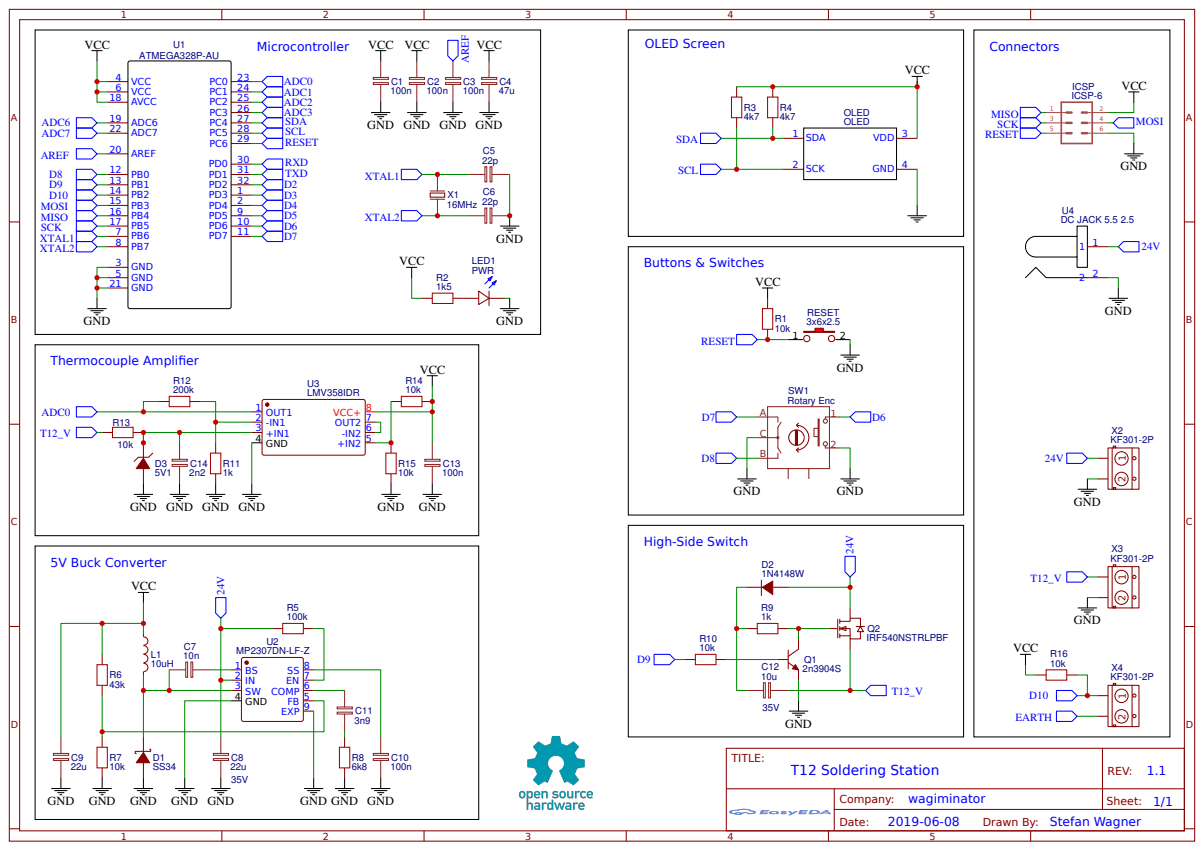
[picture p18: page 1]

Drawn By: Stefan Wagner

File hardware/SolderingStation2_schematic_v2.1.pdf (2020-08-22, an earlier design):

### VCC

### GND GND GND GND

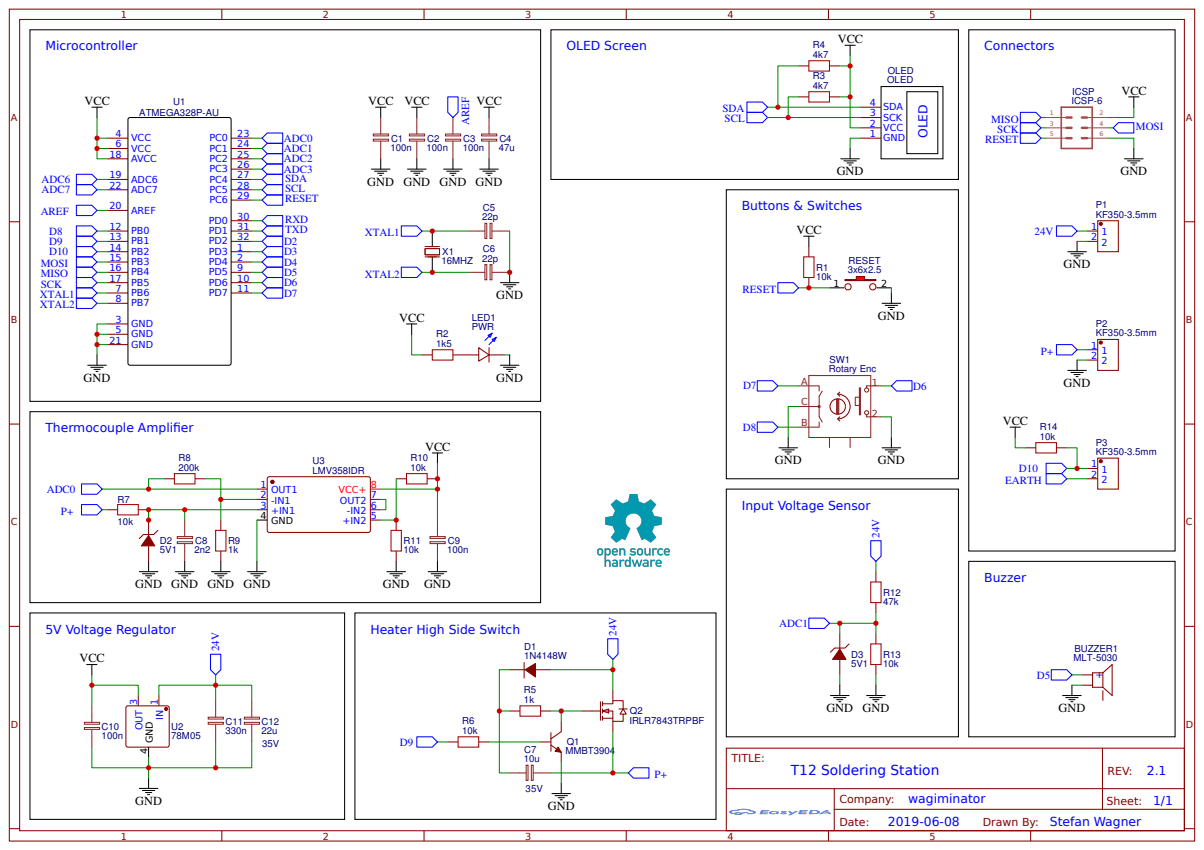
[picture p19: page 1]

GND 1 VCC 2 SCK 3 SDA 4

Drawn By: Stefan Wagner

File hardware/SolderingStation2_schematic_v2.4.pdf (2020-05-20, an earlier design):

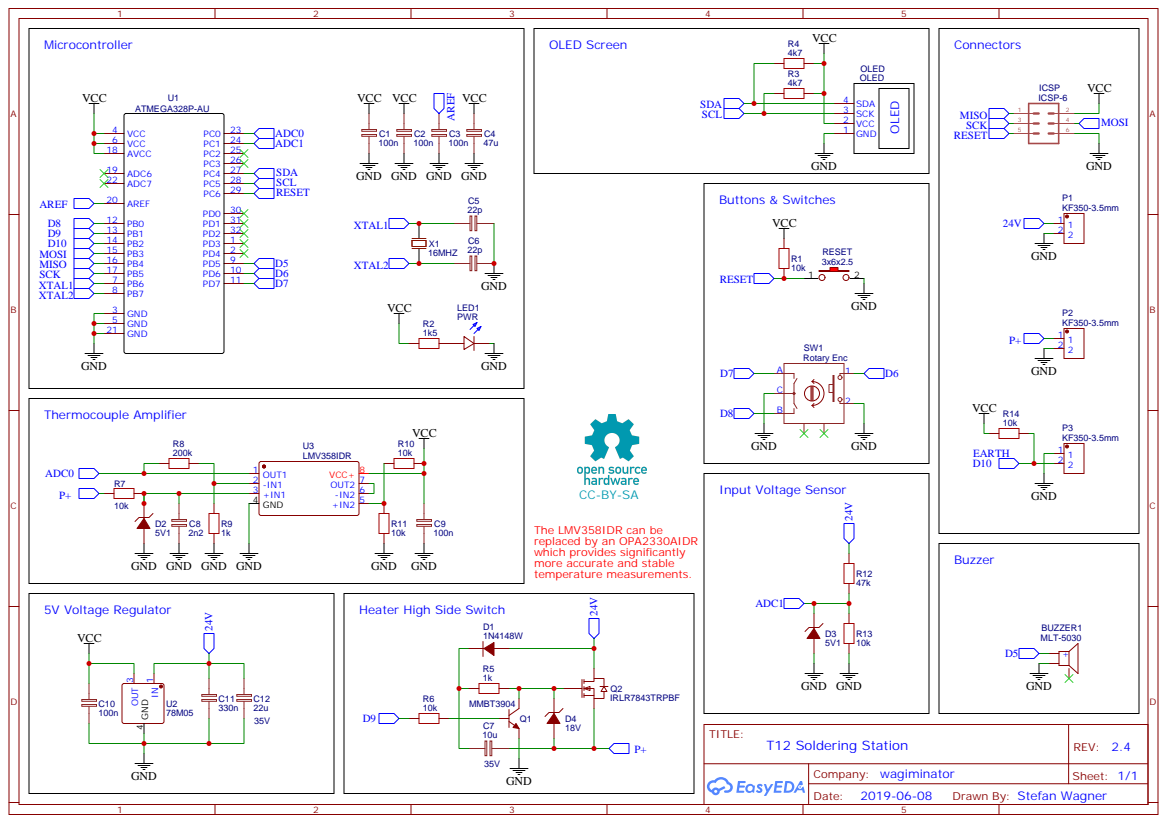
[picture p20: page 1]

GND GND

The LMV358IDR can be
replaced by an OPA2330AIDR
which provides significantly
more accurate and stable
temperature measurements.

Drawn By: Stefan Wagner

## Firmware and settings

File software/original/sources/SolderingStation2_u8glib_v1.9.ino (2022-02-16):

// SolderingStation2
//
// ATmega328-controlled Soldering Station for Hakko T12 Tips.
//
// This version of the code implements:
// - Temperature measurement of the tip
// - Direct or PID control of the heater
// - Temperature control via rotary encoder
// - Boost mode by short pressing rotary encoder switch
// - Setup menu by long pressing rotary encoder switch
// - Handle movement detection (by checking ball switch)
// - Iron unconnected detection (by idenfying invalid temperature readings)
// - Time driven sleep/power off mode if iron is unused (movement detection)
// - Measurement of input voltage, Vcc and ATmega's internal temperature
// - Information display on OLED
// - Buzzer
// - Calibrating and managing different soldering tips
// - Storing user settings into the EEPROM
// - Tip change detection
// - Can be used with either N or P channel mosfets
// - Screen flip support
// - Rotary encoder reverse support
//
// Power supply should be in the range of 16V/2A to 24V/3A and well
// stabilized.
//
// For calibration you need a soldering iron tips thermometer. For best results
// wait at least three minutes after switching on the soldering station before 
// you start the calibration process.
//
// Controller:  ATmega328p
// Core:        Barebones ATmega (https://github.com/carlosefr/atmega)
// Clockspeed:  16 MHz external
//
// It is recommended not to use a bootloader!
//
// Thank you for the code contributions:
// - John Glavinos, https://youtu.be/4YDcWfOQmz4
// - createskyblue, https://github.com/createskyblue
// - TaaraLabs, https://github.com/TaaraLabs
// - muink, https://github.com/muink
//
// 2019 - 2022 by Stefan Wagner
// Project Files (EasyEDA): https://easyeda.com/wagiminator
// Project Files (Github):  https://github.com/wagiminator
// License: http://creativecommons.org/licenses/by-sa/3.0/


// Libraries
#include <U8glib.h>             // https://github.com/olikraus/u8glib
#include <PID_v1.h>             // https://github.com/wagiminator/ATmega-Soldering-Station/blob/master/software/libraries/Arduino-PID-Library.zip 
                                // (old cpp version of https://github.com/mblythe86/C-PID-Library/tree/master/PID_v1)
#include <EEPROM.h>             // for storing user settings into EEPROM
#include <avr/sleep.h>          // for sleeping during ADC sampling

// Firmware version
#define VERSION       "v1.9"

// Type of MOSFET
#define N_MOSFET                // P_MOSFET or N_MOSFET

// Type of OLED Controller
#define SSD1306                 // SSD1306 or SH1106

// Type of rotary encoder
#define ROTARY_TYPE   1         // 0: 2 increments/step; 1: 4 increments/step (default)

// Pins
#define SENSOR_PIN    A0        // tip temperature sense
#define VIN_PIN       A1        // input voltage sense
#define BUZZER_PIN     5        // buzzer
#define BUTTON_PIN     6        // rotary encoder switch
#define ROTARY_1_PIN   7        // rotary encoder 1
#define ROTARY_2_PIN   8        // rotary encoder 2
#define CONTROL_PIN    9        // heater MOSFET PWM control
#define SWITCH_PIN    10        // handle vibration switch

// Default temperature control values (recommended soldering temperature: 300-380°C)
#define TEMP_MIN      150       // min selectable temperature
#define TEMP_MAX      400       // max selectable temperature
#define TEMP_DEFAULT  320       // default start setpoint
#define TEMP_SLEEP    150       // temperature in sleep mode
#define TEMP_BOOST     50       // temperature increase in boost mode
#define TEMP_STEP      10       // rotary encoder temp change steps

// Default tip temperature calibration values
#define TEMP200       216       // temperature at ADC = 200
#define TEMP280       308       // temperature at ADC = 280
#define TEMP360       390       // temperature at ADC = 360
#define TEMPCHP       30        // chip temperature while calibration
#define TIPMAX        8         // max number of tips
#define TIPNAMELENGTH 6         // max length of tip names (including termination)
#define TIPNAME       "BC1.5"   // default tip name

// Default timer values (0 = disabled)
#define TIME2SLEEP     5        // time to enter sleep mode in minutes
#define TIME2OFF      15        // time to shut off heater in minutes
#define TIMEOFBOOST   40        // time to stay in boost mode in seconds

// Control values
#define TIME2SETTLE   950       // time in microseconds to allow OpAmp output to settle
#define SMOOTHIE      0.05      // OpAmp output smooth factor (1=no smoothing; 0.05 default)
#define PID_ENABLE    false     // enable PID control
#define BEEP_ENABLE   true      // enable/disable buzzer
#define BODYFLIP      false     // enable/disable screen flip
#define ECREVERSE     false     // enable/disable rotary encoder reverse
#define MAINSCREEN    0         // type of main screen (0: big numbers; 1: more infos)

// EEPROM identifier
#define EEPROM_IDENT  0xE76C   // to identify if EEPROM was written by this program

// MOSFET control definitions
#if defined (P_MOSFET)         // P-Channel MOSFET
  #define HEATER_ON   255
  #define HEATER_OFF  0
  #define HEATER_PWM  255 - Output
#elif defined (N_MOSFET)       // N-Channel MOSFET
  #define HEATER_ON   0
  #define HEATER_OFF  255
  #define HEATER_PWM  Output
#else
  #error Wrong MOSFET type!
#endif

// Define the aggressive and conservative PID tuning parameters
double aggKp=11, aggKi=0.5, aggKd=1;
double consKp=11, consKi=3, consKd=5;

// Default values that can be changed by the user and stored in the EEPROM
uint16_t  DefaultTemp = TEMP_DEFAULT;
uint16_t  SleepTemp   = TEMP_SLEEP;
uint8_t   BoostTemp   = TEMP_BOOST;
uint8_t   time2sleep  = TIME2SLEEP;
uint8_t   time2off    = TIME2OFF;
uint8_t   timeOfBoost = TIMEOFBOOST;
uint8_t   MainScrType = MAINSCREEN;
bool      PIDenable   = PID_ENABLE;
bool      beepEnable  = BEEP_ENABLE;
bool      BodyFlip    = BODYFLIP;
bool      ECReverse   = ECREVERSE;

// Default values for tips
uint16_t  CalTemp[TIPMAX][4] = {TEMP200, TEMP280, TEMP360, TEMPCHP};
char      TipName[TIPMAX][TIPNAMELENGTH] = {TIPNAME};
uint8_t   CurrentTip   = 0;
uint8_t   NumberOfTips = 1;

// Menu items
const char *SetupItems[]       = { "Setup Menu", "Tip Settings", "Temp Settings",
                                   "Timer Settings", "Control Type", "Main Screen",
                                   "Buzzer", "Screen Flip", "EC Reverse", "Information", "Return" };
const char *TipItems[]         = { "Tip:", "Change Tip", "Calibrate Tip", 
                                   "Rename Tip", "Delete Tip", "Add new Tip", "Return" };
const char *TempItems[]        = { "Temp Settings", "Default Temp", "Sleep Temp", 
                                   "Boost Temp", "Return" };
const char *TimerItems[]       = { "Timer Settings", "Sleep Timer", "Off Timer", 
                                   "Boost Timer", "Return" };
const char *ControlTypeItems[] = { "Control Type", "Direct", "PID" };
const char *MainScreenItems[]  = { "Main Screen", "Big Numbers", "More Infos" };
const char *StoreItems[]       = { "Store Settings ?", "No", "Yes" };
const char *SureItems[]        = { "Are you sure ?", "No", "Yes" };
const char *BuzzerItems[]      = { "Buzzer", "Disable", "Enable" };
const char *FlipItems[]        = { "Screen Flip", "Disable", "Enable" };
const char *ECReverseItems[]   = { "EC Reverse", "Disable", "Enable" };
const char *DefaultTempItems[] = { "Default Temp", "\xB0""C" };
const char *SleepTempItems[]   = { "Sleep Temp", "\xB0""C" };
const char *BoostTempItems[]   = { "Boost Temp", "\xB0""C" };
const char *SleepTimerItems[]  = { "Sleep Timer", "Minutes" };
const char *OffTimerItems[]    = { "Off Timer", "Minutes" };
const char *BoostTimerItems[]  = { "Boost Timer", "Seconds" };
const char *DeleteMessage[]    = { "Warning", "You cannot", "delete your", "last tip!" };
const char *MaxTipMessage[]    = { "Warning", "You reached", "maximum number", "of tips!" };

// Variables for pin change interrupt
volatile uint8_t  a0, b0, c0, d0;
volatile bool     ab0;
volatile int      count, countMin, countMax, countStep;
volatile bool     handleMoved;
 
// Variables for temperature control
uint16_t  SetTemp, ShowTemp, gap, Step;
double    Input, Output, Setpoint, RawTemp, CurrentTemp, ChipTemp;

// Variables for voltage readings
uint16_t  Vcc, Vin;
 
// State variables
bool      inSleepMode = false;
bool      inOffMode   = false;
bool      inBoostMode = false;
bool      inCalibMode = false;
bool      isWorky     = true;
bool      beepIfWorky = true;
bool      TipIsPresent= true;

// Timing variables
uint32_t  sleepmillis;
uint32_t  boostmillis;
uint32_t  buttonmillis;
uint8_t   goneMinutes;
uint8_t   goneSeconds;
uint8_t   SensorCounter = 255;

// Specify variable pointers and initial PID tuning parameters
PID ctrl(&Input, &Output, &Setpoint, aggKp, aggKi, aggKd, REVERSE);
 
// Setup u8g object depending on OLED controller
#if defined (SSD1306)
  U8GLIB_SSD1306_128X64 u8g(U8G_I2C_OPT_DEV_0|U8G_I2C_OPT_NO_ACK|U8G_I2C_OPT_FAST);
#elif defined (SH1106)
  U8GLIB_SH1106_128X64 u8g(U8G_I2C_OPT_FAST|U8G_I2C_OPT_NO_ACK);
#else
  #error Wrong OLED controller type!
#endif


void setup() { 
  // set the pin modes
  pinMode(SENSOR_PIN,   INPUT);
  pinMode(VIN_PIN,      INPUT);
  pinMode(BUZZER_PIN,   OUTPUT);
  pinMode(CONTROL_PIN,  OUTPUT);
  pinMode(ROTARY_1_PIN, INPUT_PULLUP);
  pinMode(ROTARY_2_PIN, INPUT_PULLUP);
  pinMode(BUTTON_PIN,   INPUT_PULLUP);
  pinMode(SWITCH_PIN,   INPUT_PULLUP);
  
  analogWrite(CONTROL_PIN, HEATER_OFF); // this shuts off the heater
  digitalWrite(BUZZER_PIN, LOW);        // must be LOW when buzzer not in use

  // setup ADC
  ADCSRA |= bit (ADPS0) | bit (ADPS1) | bit (ADPS2);  // set ADC prescaler to 128
  ADCSRA |= bit (ADIE);                 // enable ADC interrupt
  interrupts ();                        // enable global interrupts

  // setup pin change interrupt for rotary encoder
  PCMSK0 = bit (PCINT0);                // Configure pin change interrupt on Pin8
  PCICR  = bit (PCIE0);                 // Enable pin change interrupt
  PCIFR  = bit (PCIF0);                 // Clear interrupt flag

  // prepare and start OLED
  if      ( u8g.getMode() == U8G_MODE_R3G3B2 )   u8g.setColorIndex(255);
  else if ( u8g.getMode() == U8G_MODE_GRAY2BIT ) u8g.setColorIndex(3);
  else if ( u8g.getMode() == U8G_MODE_BW )       u8g.setColorIndex(1);
  else if ( u8g.getMode() == U8G_MODE_HICOLOR )  u8g.setHiColorByRGB(255,255,255);

  // get default values from EEPROM
  getEEPROM();

  // set screen flip
  SetFlip();

  // read supply voltages in mV
  Vcc = getVCC(); Vin = getVIN();

  // read and set current iron temperature
  SetTemp  = DefaultTemp;
  RawTemp  = denoiseAnalog(SENSOR_PIN);
  ChipTemp = getChipTemp();
  calculateTemp();

  // turn on heater if iron temperature is well below setpoint
  if ((CurrentTemp + 20) < DefaultTemp) analogWrite(CONTROL_PIN, HEATER_ON);

  // set PID output range and start the PID
  ctrl.SetOutputLimits(0, 255);
  ctrl.SetMode(AUTOMATIC);

  // set initial rotary encoder values
  a0 = PINB & 1; b0 = PIND>>7 & 1; ab0 = (a0 == b0);
  setRotary(TEMP_MIN, TEMP_MAX, TEMP_STEP, DefaultTemp);
  
  // reset sleep timer
  sleepmillis = millis();

  // long beep for setup completion
  beep(); beep();
}
 

void loop() {
  ROTARYCheck();      // check rotary encoder (temp/boost setting, enter setup menu)
  SLEEPCheck();       // check and activate/deactivate sleep modes
  SENSORCheck();      // reads temperature and vibration switch of the iron
  Thermostat();       // heater control
  MainScreen();       // updates the main page on the OLED
}




// check rotary encoder; set temperature, toggle boost mode, enter setup menu accordingly
void ROTARYCheck() {
  // set working temperature according to rotary encoder value
  SetTemp = getRotary();
  
  // check rotary encoder switch
  uint8_t c = digitalRead(BUTTON_PIN);
  if ( !c && c0 ) {
    beep();
    buttonmillis = millis();
    while( (!digitalRead(BUTTON_PIN)) && ((millis() - buttonmillis) < 500) );
    if ((millis() - buttonmillis) >= 500) SetupScreen();
    else {
      inBoostMode = !inBoostMode;
      if (inBoostMode) boostmillis = millis();
      handleMoved = true;
    }
  }
  c0 = c;

  // check timer when in boost mode
  if (inBoostMode && timeOfBoost) {
    goneSeconds = (millis() - boostmillis) / 1000;
    if (goneSeconds >= timeOfBoost) {
      inBoostMode = false;              // stop boost mode
      beep();                           // beep if boost mode is over
      beepIfWorky = true;               // beep again when working temperature is reached
    }
  }
}


// check and activate/deactivate sleep modes
void SLEEPCheck() {
  if (handleMoved) {                    // if handle was moved
    if (inSleepMode) {                  // in sleep or off mode?
      if ((CurrentTemp + 20) < SetTemp) // if temp is well below setpoint
        analogWrite(CONTROL_PIN, HEATER_ON);    // then start the heater right now
      beep();                           // beep on wake-up
      beepIfWorky = true;               // beep again when working temperature is reached
    }
    handleMoved = false;                // reset handleMoved flag
    inSleepMode = false;                // reset sleep flag
    inOffMode   = false;                // reset off flag
    sleepmillis = millis();             // reset sleep timer
  }

  // check time passed since the handle was moved
  goneMinutes = (millis() - sleepmillis) / 60000;
  if ( (!inSleepMode) && (time2sleep > 0) && (goneMinutes >= time2sleep) ) {inSleepMode = true; beep();}
  if ( (!inOffMode)   && (time2off   > 0) && (goneMinutes >= time2off  ) ) {inOffMode   = true; beep();}
}


// reads temperature, vibration switch and supply voltages
void SENSORCheck() {
  analogWrite(CONTROL_PIN, HEATER_OFF);       // shut off heater in order to measure temperature
  delayMicroseconds(TIME2SETTLE);             // wait for voltage to settle
  
  double temp = denoiseAnalog(SENSOR_PIN);    // read ADC value for temperature
  uint8_t d = digitalRead(SWITCH_PIN);        // check handle vibration switch
  if (d != d0) {handleMoved = true; d0 = d;}  // set flag if handle was moved
  if (! SensorCounter--) Vin = getVIN();      // get Vin every now and then
  
  analogWrite(CONTROL_PIN, HEATER_PWM);       // turn on again heater
  
  RawTemp += (temp - RawTemp) * SMOOTHIE;     // stabilize ADC temperature reading
  calculateTemp();                            // calculate real temperature value

  // stabilize displayed temperature when around setpoint
  if ((ShowTemp != Setpoint) || (abs(ShowTemp - CurrentTemp) > 5)) ShowTemp = CurrentTemp;
  if (abs(ShowTemp - Setpoint) <= 1) ShowTemp = Setpoint;

  // set state variable if temperature is in working range; beep if working temperature was just reached
  gap = abs(SetTemp - CurrentTemp);
  if (gap < 5) {
    if (!isWorky && beepIfWorky) beep();
    isWorky = true;
    beepIfWorky = false;
  }
  else isWorky = false;

  // checks if tip is present or currently inserted
  if (ShowTemp > 500) TipIsPresent = false;   // tip removed ?
  if (!TipIsPresent && (ShowTemp < 500)) {    // new tip inserted ?
    analogWrite(CONTROL_PIN, HEATER_OFF);     // shut off heater
    beep();                                   // beep for info
    TipIsPresent = true;                      // tip is present now
    ChangeTipScreen();                        // show tip selection screen
    updateEEPROM();                           // update setting in EEPROM
    handleMoved = true;                       // reset all timers
    RawTemp  = denoiseAnalog(SENSOR_PIN);     // restart temp smooth algorithm
    c0 = LOW;                                 // switch must be released
    setRotary(TEMP_MIN, TEMP_MAX, TEMP_STEP, SetTemp);  // reset rotary encoder
  }
}


// calculates real temperature value according to ADC reading and calibration values
void calculateTemp() {
  if      (RawTemp < 200) CurrentTemp = map (RawTemp,   0, 200,                     21, CalTemp[CurrentTip][0]);
  else if (RawTemp < 280) CurrentTemp = map (RawTemp, 200, 280, CalTemp[CurrentTip][0], CalTemp[CurrentTip][1]);
  else                    CurrentTemp = map (RawTemp, 280, 360, CalTemp[CurrentTip][1], CalTemp[CurrentTip][2]);
}


// controls the heater
void Thermostat() {
  // define Setpoint acoording to current working mode
  if      (inOffMode)   Setpoint = 0;
  else if (inSleepMode) Setpoint = SleepTemp;
  else if (inBoostMode) Setpoint = SetTemp + BoostTemp;
  else                  Setpoint = SetTemp; 

  // control the heater (PID or direct)
  gap = abs(Setpoint - CurrentTemp);
  if (PIDenable) {
    Input = CurrentTemp;
    if (gap < 30) ctrl.SetTunings(consKp, consKi, consKd);
    else ctrl.SetTunings(aggKp, aggKi, aggKd); 
    ctrl.Compute();
  } else {
    // turn on heater if current temperature is below setpoint
    if ((CurrentTemp + 0.5) < Setpoint) Output = 0; else Output = 255;
  }
  analogWrite(CONTROL_PIN, HEATER_PWM);     // set heater PWM
}


// creates a short beep on the buzzer
void beep(){
  if (beepEnable) {
    for (uint8_t i=0; i<255; i++) {
      digitalWrite(BUZZER_PIN, HIGH);
      delayMicroseconds(125);
      digitalWrite(BUZZER_PIN, LOW);
      delayMicroseconds(125);
    }
  }
}


// sets start values for rotary encoder
void setRotary(int rmin, int rmax, int rstep, int rvalue) {
  countMin  = rmin << ROTARY_TYPE;
  countMax  = rmax << ROTARY_TYPE;
  countStep = ECReverse ? -rstep : rstep;
  count     = rvalue << ROTARY_TYPE;  
}


// reads current rotary encoder value
int getRotary() {
  return (count >> ROTARY_TYPE);
}


// reads user settings from EEPROM; if EEPROM values are invalid, write defaults
void getEEPROM() {
  uint16_t identifier = (EEPROM.read(0) << 8) | EEPROM.read(1);
  if (identifier == EEPROM_IDENT) {
    DefaultTemp = (EEPROM.read(2) << 8) | EEPROM.read(3);
    SleepTemp   = (EEPROM.read(4) << 8) | EEPROM.read(5);
    BoostTemp   =  EEPROM.read(6);
    time2sleep  =  EEPROM.read(7);
    time2off    =  EEPROM.read(8);
    timeOfBoost =  EEPROM.read(9);
    MainScrType =  EEPROM.read(10);
    PIDenable   =  EEPROM.read(11);
    beepEnable  =  EEPROM.read(12);
    BodyFlip    =  EEPROM.read(13);
    ECReverse   =  EEPROM.read(14);
    CurrentTip  =  EEPROM.read(15);
    NumberOfTips = EEPROM.read(16);

    uint8_t i, j;
    uint16_t counter = 17;
    for (i = 0; i < NumberOfTips; i++) {
      for (j = 0; j < TIPNAMELENGTH; j++) {
        TipName[i][j] = EEPROM.read(counter++);
      }
      for (j = 0; j < 4; j++) {
        CalTemp[i][j]  = EEPROM.read(counter++) << 8;
        CalTemp[i][j] |= EEPROM.read(counter++);
      }
    }
  }
  else {
    EEPROM.update(0, EEPROM_IDENT >> 8); EEPROM.update(1, EEPROM_IDENT & 0xFF);
    updateEEPROM();
  }
}


// writes user settings to EEPROM using updade function to minimize write cycles
void updateEEPROM() {
  EEPROM.update( 2, DefaultTemp >> 8);
  EEPROM.update( 3, DefaultTemp & 0xFF);
  EEPROM.update( 4, SleepTemp >> 8);
  EEPROM.update( 5, SleepTemp & 0xFF);
  EEPROM.update( 6, BoostTemp);
  EEPROM.update( 7, time2sleep);
  EEPROM.update( 8, time2off);
  EEPROM.update( 9, timeOfBoost);
  EEPROM.update(10, MainScrType);
  EEPROM.update(11, PIDenable);
  EEPROM.update(12, beepEnable);
  EEPROM.update(13, BodyFlip);
  EEPROM.update(14, ECReverse);
  EEPROM.update(15, CurrentTip);
  EEPROM.update(16, NumberOfTips);

  uint8_t i, j;
  uint16_t counter = 17;
  for (i = 0; i < NumberOfTips; i++) {
    for (j = 0; j < TIPNAMELENGTH; j++) EEPROM.update(counter++, TipName[i][j]);
    for (j = 0; j < 4; j++) {
      EEPROM.update(counter++, CalTemp[i][j] >> 8);
      EEPROM.update(counter++, CalTemp[i][j] & 0xFF);
    }
  }
}


// check state and flip screen
void SetFlip() {
  if (BodyFlip) u8g.setRot180();
  else          u8g.undoRotation();
}


// draws the main screen
void MainScreen() {
  u8g.firstPage();
  do {
    // draw setpoint temperature
    u8g.setFont(u8g_font_9x15);
    u8g.setFontPosTop();
    u8g.drawStr( 0, 0,  "SET:");
    u8g.setPrintPos(40,0);
    u8g.print(Setpoint, 0);

    // draw status of heater
    u8g.setPrintPos(83,0);
    if (ShowTemp > 500)    u8g.print(F("ERROR"));
    else if (inOffMode)    u8g.print(F("  OFF"));
    else if (inSleepMode)  u8g.print(F("SLEEP"));
    else if (inBoostMode)  u8g.print(F("BOOST"));
    else if (isWorky)      u8g.print(F("WORKY"));
    else if (Output < 180) u8g.print(F(" HEAT"));
    else                   u8g.print(F(" HOLD"));

    // rest depending on main screen type
    if (MainScrType) {
      // draw current tip and input voltage
      float fVin = (float)Vin / 1000;     // convert mv in V
      u8g.setPrintPos( 0,52); u8g.print(TipName[CurrentTip]);
      u8g.setPrintPos(83,52); u8g.print(fVin, 1); u8g.print(F("V"));
      // draw current temperature
      u8g.setFont(u8g_font_freedoomr25n);
      u8g.setFontPosTop();
      u8g.setPrintPos(37,22);
      if (ShowTemp > 500) u8g.print(F("000")); else u8g.print(ShowTemp);
    } else {
      // draw current temperature in big figures
      u8g.setFont(u8g_font_fub42n);
      u8g.setFontPosTop();
      u8g.setPrintPos(15,20);
      if (ShowTemp > 500) u8g.print(F("000")); else u8g.print(ShowTemp);
    }
  } while(u8g.nextPage());
}
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

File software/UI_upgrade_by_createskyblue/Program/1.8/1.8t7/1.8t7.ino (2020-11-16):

/*License: http://creativecommons.org/licenses/by-sa/3.0/
   采用CC3.0协议共享此程序
   您可以自由地
  共享 — 在任何媒介以任何形式复制、发行本作品
  演绎 — 修改、翻译或以本作品为基础进行创作
  在任何用途下，甚至商业目的。
  本许可协议为“自由文化作品（Free Cultural Works）”所接受。
  只要你遵守许可协议条款，许可人就无法收回你的这些权利。

  Attribution-ShareAlike 3.0 Unported (CC BY-SA 3.0)
  This is a human-readable summary of (and not a substitute for) the license. Disclaimer.
  You are free to:
  Share — copy and redistribute the material in any medium or format
  Adapt — remix, transform, and build upon the material
  for any purpose, even commercially.
  This license is acceptable for Free Cultural Works.
  The licensor cannot revoke these freedoms as long as you follow the license terms.
*/
// SolderingStation2
//
// ATmega328-controlled Soldering Station for Hakko T12 Tips.
// 此v1.8t7版本功能简介
// This 1.8t7 version of the code implements:
// - 烙铁头温度实时监测
// - Temperature measurement of the tip
// - PID温度控制
// - Direct or PID control of the heater
// - 可以通过编码器进行控制温度
// - Temperature control via rotary encoder
// - 短按编码器进入短时升温模式
// - Boost mode by short pressing rotary encoder switch
// - 长按编码器进入主菜单
// - Setup menu by long pressing rotary encoder switch
// - 手柄震动检测（需要手柄含有震动传感器）
// - Handle movement detection (by checking ball switch)
// - 手柄连接检测（通过判断烙铁头温度是否能够被读取来实现）
// - Iron unconnected detection (by idenfying invalid temperature readings)
// - 定时器设定 - 随眠，关机时间
// - Time driven sleep/power off mode if iron is unused (movement detection)
// - 可以测量主控芯片电压以及温度
// - Measurement of input voltage, Vcc and ATmega's internal temperature
// - 在OLED上实现信息显示
// - Information display on OLED
// - 支持无源蜂鸣器
// - Buzzer
// - 允许设置不同烙铁头的温度校准值
// - Calibrating and managing different soldering tips
// - 设置被保存在EEPROM，掉电不丢失
// - Storing user settings into the EEPROM
// - 允许热插拔烙铁头，并弹出烙铁头配置选择菜单
// - Tip change detection
// - 芯片过热以及低电压报警
// - Chip overheating and low voltage alarm
// - 更好的实时温度条以及实时功率条
// - Better real-time temperature bar and real-time power bar
// - 拥有过渡动画
// - Have transition animation
// - 内置屏幕保护程序
// - Built in screen saver
// - 屏幕翻转设置
// - Screen flip settings
// - 内置英文、中文、日文语言包
// - Built in English, Chinese and Japanese language pack
// - 开机密码设置
// - System Password
// - 允许设置旋钮方向
// - Knob direction setting menu
// - 内嵌看门狗，宕机自动重启
// - Watchdog timer automatic reset the MCU

// - V1.8t7 New features:
// ------ EEPROM可用性检查机制
// ------ EEPROM availability check

// ------ 允许保存最大30个烙铁头的配置
// ------ 30 preservable soldering tip configurations

// ------ 9段温度曲线拟合
// ------ 9 segments of temperature curve fitting

/*
增加"EEPROM"和"RESET." 指令，可以给标签命名为指令的名字，点击标签即可执行
关于"EEPROM"指令:查看EEPROM内容
关于"RESET."指令：重置EEPROM *警告！ 你会失去所有烙铁头的温度校准数据!!!

Add "EEPROM" and "RESET." to give the label the name of the instruction. Click the label to execute
Regarding "EEPROM" instruction: View EEPROM contents
Regarding "RESET." instruction: RESET EEPROM 
* warning! You will lose all the temperature calibration data for the tip of the soldering iron!!
*/


// Power supply should be in the range of 16V/2A to 24V/3A and well
// stabilized.
//
// For calibration you need a soldering iron tips thermometer. For best results
// wait at least three minutes after switching on the soldering station before
// you start the calibration process.
//
// Controller:  ATmega328p
// Core:        Barebones ATmega (https://github.com/carlosefr/atmega)
// Clockspeed:  16 MHz external
//
// 2019/2020 by Stefan Wagner with great support from John Glavinos
// 2020-8 UI upgrade by LHW-createskyblue 、lihaoyun6
// Project Page: https://easyeda.com/wagiminator


bool lastbutton;
#include <Arduboy2.h>  //注意 这里使用被阉割的图形库，只有绘图功能，并非通用的版本
Arduboy2 arduboy;

#include <EEPROM.h>
#include <PID_v1.h>
#include <avr/sleep.h>
// Firmware version
#define VERSION       "v1.8t7"

// Type of rotary encoder
#define ROTARY_TYPE   1         // 0: 2 increments/step; 1: 4 increments/step

// Pins
#define SENSOR_PIN    A0        // temperature sense
#define VIN_PIN       A1        // input voltage sense
#define BUZZER_PIN     5        // buzzer
#define BUTTON_PIN     6        // rotary encoder switch
#define ROTARY_1_PIN   7        // rotary encoder 1
#define ROTARY_2_PIN   8        // rotary encoder 2
#define CONTROL_PIN    9        // heater MOSFET PWM control
#define SWITCH_PIN    10        // handle vibration switch

// Default temperature control values (recommended soldering temperature: 300-380°C)
#define TEMP_MIN      100       // min selectable temperature
#define TEMP_MAX      400       // max selectable temperature
#define TEMP_DEFAULT  320       // default start setpoint
#define TEMP_SLEEP    150       // temperature in sleep mode
#define TEMP_BOOST     60       // temperature increase in boost mode
#define TEMP_STEP      5       // rotary encoder temp change steps

// Default tip temperature calibration values
#define TEMPCHP       30        // chip temperature while calibration
#define TIPMAX        30         // max number of tips
#define TIPNAMELENGTH 7         // max length of tip names (including termination)
#define TIPNAME       "SZtip"   // default tip name


// Default timer values (0 = disabled)
#define TIME2SLEEP     5        // time to enter sleep mode in minutes
#define TIME2OFF      15        // time to shut off heater in minutes
#define TIMEOFBOOST   40        // time to stay in boost mode in seconds

// Control values
#define TIME2SETTLE   950       // time in microseconds to allow OpAmp output to settle
#define SMOOTHIE      0.05      // OpAmp output smooth factor (1=no smoothing; 0.05 default)
#define PID_ENABLE    true      // enable PID control
#define BEEP_ENABLE   true      // enable/disable buzzer
#define MAINSCREEN    1         // type of main screen (0: big numbers; 1: more infos)

// EEPROM identifier
#define EEPROM_IDENT   0x140C   // to identify if EEPROM was written by this program

//Beep
#define SetBeepCoolTime 200
unsigned long BeepCoolTime;

// Define the aggressive and conservative PID tuning parameters
double aggKp = 11, aggKi = 0.5, aggKd = 1;
double consKp = 11, consKi = 3, consKd = 5;

// Default values that can be changed by the user and stored in the EEPROM
uint16_t  DefaultTemp = TEMP_DEFAULT;
uint16_t  SleepTemp   = TEMP_SLEEP;
uint8_t   BoostTemp   = TEMP_BOOST;
uint8_t   Time2sleep  = TIME2SLEEP;
uint8_t   Time2off    = TIME2OFF;
uint8_t   TimeOfBoost = TIMEOFBOOST;
uint8_t   MainScrType = MAINSCREEN;
bool      PIDenable   = PID_ENABLE;
bool      BeepEnable  = BEEP_ENABLE;

//温度拟合
#define TempP1 10.2675914764
#define TempP2 1.7323191166
#define TempP3 -0.0033245713
#define TempP4 0.0000045338
float    PTemp[4] = {TempP1, TempP2, TempP3, TempP4}; //温度拟合系数
const uint16_t CalTemp[9] = {50, 100, 150, 200, 250, 300, 350, 400, 450};
char      TipName[TIPNAMELENGTH] = {TIPNAME};
uint8_t   CurrentTip   = 0;
uint8_t   NumberOfTips = 1;
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

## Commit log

2020-06-21 Upload new version
    [SolderingStation2_BOM_v2.5.csv]
2020-08-16 更好的UI
2020-08-16 UI Upgrade
    1. Beautify the detail page and increase the power bar
    2. Menus have ICONS
    3. Better scrolling animation
    4. Get rid of the U8g graphics library and use the ArduBoy graphics
    Library (Lite) to improve the frame rate and reduce memory usage to make
    graphics possible
    5. Add flip display Settings to adapt to the habits of different people
    6. Add multilingual support for English and Chinese
2020-08-16 Update README.md
    增加中文警告，提示此版本存在的缺陷
2020-08-16 Numerical scrolling effect
    1. Modify the scrolling direction to make the scrolling more coordinated
    with the number size change
    2. The main page also USES numerical scrolling in the simplified mode to
    make the temperature change more vivid
2020-08-16 Simple display mode Update
    简洁显示模式中加入数值滚动以及状态条
    Simple display mode with numeric scrolling and status bar
2020-08-16 Update files
    [SolderingStation2_BOM_v2.6.csv]
2020-08-17 English is Back！！！
    Once in order to add cool graphical interface, Chinese and even
    animation to make memory tight, it is not necessary to delete part of
    the English support.
    But after thrilling optimization
    (the project uses
    32234 bytes and takes up (99%) program storage space. Up to 32256
    bytes)
    95% of English support is back (5% due to the removal of the
    message screen function)
    It's more difficult to scan the x648
    code
    (nobody knows compression better than I do)
    At the same time, this
    version optimizes some animation experience!
    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
    [SolderingStation2_arduboy_gplib_v1.6L.ino]
2020-08-18 Fix Menu Text Size
    [SolderingStation2_arduboy_gplib_v1.6L.ino]
2020-08-21 Update alarm
    1.移除二维码节省内存
    2.增加可设置的欠压提醒，方便使用电池供电的用户
    3.增加强制芯片过热提醒，芯片温度>80摄氏度时触发
    4.在信息详细模式中报警时对应的图标闪烁
    感谢由 甘草酸不酸 提供的建议
    //////////////////////////////////////////////////
    1. Remove QR code to save memory
    2. Add a set of undervoltage reminder to facilitate battery powered
    users
    3. Add the forced chip overheat warning, trigger when chip temperature >
    80 ℃
    4. in the detailed information mode, the corresponding icon is flashing
    when the alarm is given.
    Thanks for the advice from 甘草酸不酸
    [SolderingStation2_arduboy_gplib_v1.6L+.ino]
2020-08-23 提交位图素材
    方便二次创作
2020-08-24 Update Icon
    在 千年板蓝根 的帮助下我们重置了状态栏图标
    With the help of 千年板蓝根, we recreated the status bar icon
2020-08-25 V1.7 beta
    1.由画师lihaoyun6的帮助下我们重置菜单图标，统一风格，并通过降低分辨率的形式来达到减少内存使用的目的，为未来更多功能的加入创造了可能性
    2.修复英语模式中潜在的内存越界BUG
    ////////////////////////////////////////////////////
    1. With the help of painter lihaoyun6, we recreate the menu icon, unify
    the style, and reduce the memory usage by reducing the resolution, which
    creates the possibility of adding more functions in the future
    2. Fix
    the potential memory overrun bug in English mode
    [SolderingStation2_arduboy_gplib_v1.7t1.ino]
2020-08-25 v1.7 beta 2
    修复动画显示异常
    [SolderingStation2_arduboy_gplib_v1.7t2.ino]
2020-08-25 Add Japanese -.v1.7t3
    使用了emutyworks的日语字库，添加日语支持
    The Japanese font library of emutyworks is
    used to add Japanese support
    修复一些内存越界的问题
    Fixed some memory overruns
    [SolderingStation2_arduboy_gplib_v1.7t3.ino]
2020-08-25 修改翻转选择方式 Modify flip selection method
    删除翻转选择菜单，现在只需单击翻转即可翻转
    Remove the flip selection menu, and now just click flip to flip
    [SolderingStation2_arduboy_gplib_v1.7t4.ino]
2020-08-30 v1.7+ 正式版 Official version
    屏幕保护程序
    Screen saver
    英文、中文、日文语言包
    English, Chinese and Japanese language pack
    开机密码设置
    System Password
    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
2020-09-01 修复文字显示错位
2020-09-12 修复预编译文件到最新版本
    上一次更新源代码的时候忘记更新二进制文件
2020-09-26 Organize folders 整理文件
2020-09-26 1.8t1 目标
2020-09-28 探究简约模式配色方案
2020-09-29 v1.8t1
    更新旋钮方向设置界面
2020-09-29 调整一些细节
2020-09-29 Uiv1.8t1 同步 源v1.7更新
    优化温度波动显示
2020-09-29 更新预编译的固件
    v1.8t1 更新告一段落
2020-09-29 更新版本号
2020-10-02 优化警报系统
2020-10-06 v1.8t3 WDT
    WatchDogTimer
    加入自动复位看门狗，可在存在非致命错误的宕机中自动复位
2020-10-06 修正不正确的版本号显示
2020-10-13 v1.8t4
    1 增加对PMOS的支持
    2 修复到达预定温度后蜂鸣器只响一次的历史遗留bug
    [1.8t4.ino]
2020-10-29 V1.8t5 fixed voltage display overflow problem
    V1.8t5 fixed voltage display overflow problem
    [1.8t5.ino]
2020-10-31 修复版本号显示滞后的问题
2020-11-14 v1.8t7
    1.校准模式增加9段温度曲线拟合，使温度读数更加精准
    Add 9 sections of temperature curve fitting to the calibration mode to make the temperature reading more accurate
    2.烙铁头设定数量增加到30个上限
    Increase the number of tips to 30
2020-11-14 暂时修复校准后内存溢出的问题
    通过校准后自动重启缓解这个问题
2020-11-14 更明显的报错提示
2020-11-14 回退电源电压读取函数
2020-11-14 Revert "回退电源电压读取函数"
    This reverts commit d969e85e288846a02e607bc880f2f0821a893009.
    [F.ino]
2020-11-14 增加内存检查机制 Increased EEPROM memory check
    增加内存检查机制
    Increased EEPROM memory check
2020-11-14 增加内存检查机制
    修复判定语句的错误
2020-11-15 更改默认界面配色Change the default interface color scheme
    1.主界面默认黑色底
    2.增加主报警屏幕闪烁
    3.增加两条可输入指令
    EEPROM-查看EEPROM内存
    RESET. -重置数据
    1. Default black background on the main interface
    2. Increase flicker of main alarm screen
    3. Add two input instructions, respectively
    EEPROM- View EEPROM memory
    RESET. - RESET data
    [1.8t7.ino, D-EEProm.ino, GUI.ino]
2020-11-15 删除版本滞后的压缩文件
2020-11-15 增加描述文件
2020-11-15 Revert "增加描述文件"
    This reverts commit 3167f58e84fca91a765ecfbae6c82fe5bbc11de0.
    [1.8t7.ino]
2020-11-15 Revert "Revert "增加描述文件""
    This reverts commit 8fabd9326437cec33eb0793e74734140aa2fb67b.
    [1.8t7.ino]
2020-11-15 Revert "Merge remote-tracking branch 'wagiminator/master'"
    This reverts commit 473853ed2d7cb598b5661ce1725a0ae4abb00af8, reversing
    changes made to 3167f58e84fca91a765ecfbae6c82fe5bbc11de0.
    [1.8t3.ino]
2021-04-04 Added support for P-Channel Mosfets
    Added link to the working PID library archive since the original library has changed and does not work anymore
    [SolderingStation2_u8glib_v1.7.ino]
2021-04-05 Added support for P-Channel Mosfets (by TaaraLabs)
2022-02-13 Added screen flip support
    [SolderingStation2_u8glib_v1.8.ino]
2022-02-13 Added Rotary encoder reverse support
    [SolderingStation2_u8glib_v1.8.ino]
